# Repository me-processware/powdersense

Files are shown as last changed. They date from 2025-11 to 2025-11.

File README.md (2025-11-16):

# PowderSense - Open Source Precision Measurement System

**Developer**: Processware  
**License**: CERN-OHL-W (Hardware), MIT (Software), CC BY-SA 4.0 (Documentation)  
**Version**: 1.0  
**Status**: Active Development

---

## 📸 Product Overview

<p align="center">
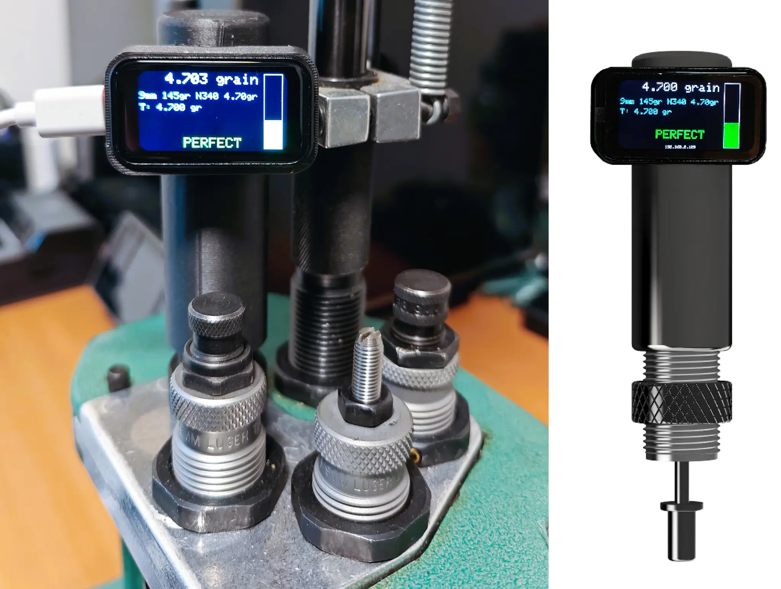
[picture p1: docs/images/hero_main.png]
PowderSense in Action
  
</p>

**PowderSense** mounted on a reloading press, showing real-time precision measurement with visual feedback. The device features a 1.47" color display, WiFi connectivity, and professional PLA-CF enclosure.

---

## 🕹️ Display States

<p align="center">
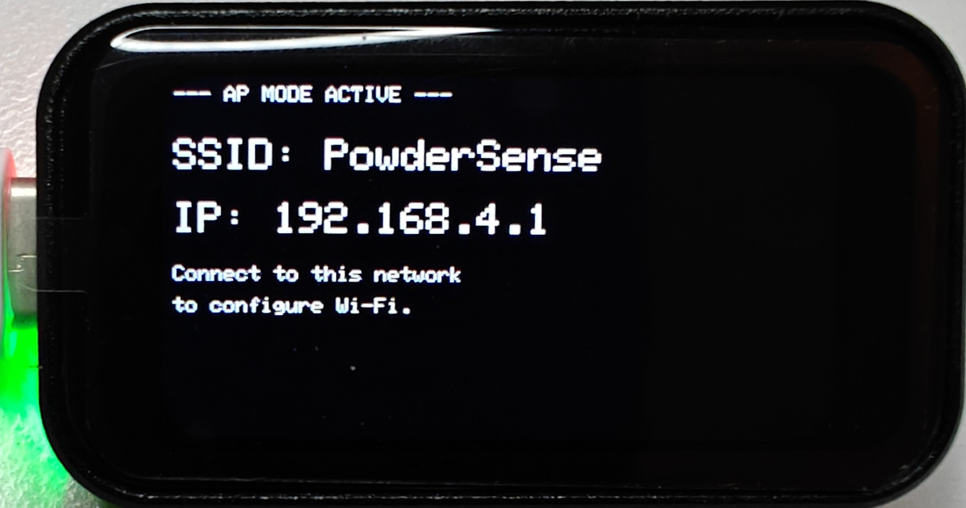
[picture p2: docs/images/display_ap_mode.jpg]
AP Mode
  
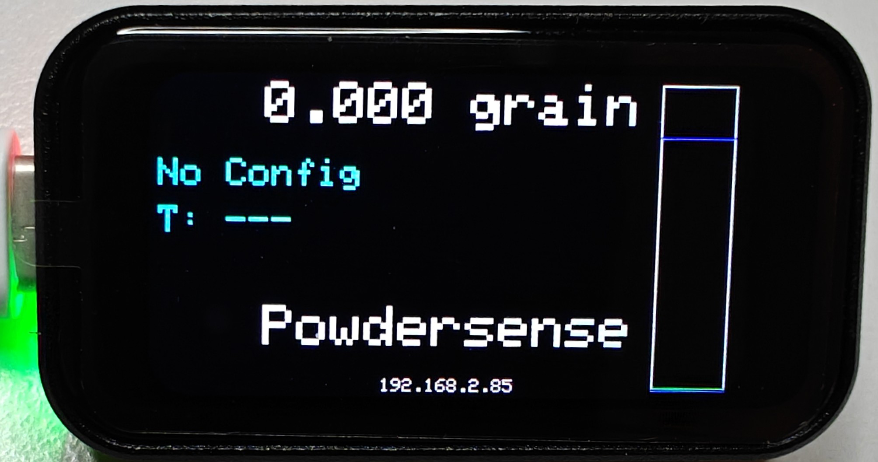
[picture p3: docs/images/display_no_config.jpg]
No Config
  
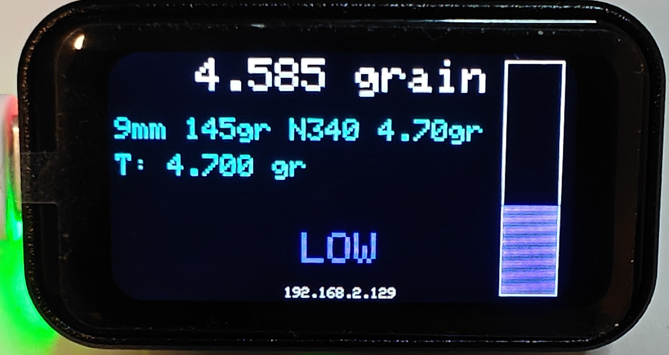
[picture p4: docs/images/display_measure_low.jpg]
Measure Low
  
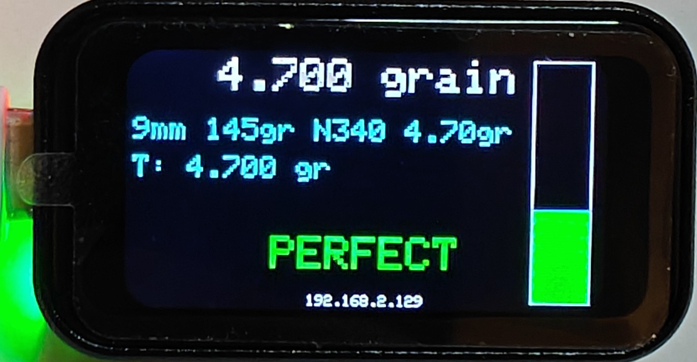
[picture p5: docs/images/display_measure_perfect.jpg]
Measure Perfect
  
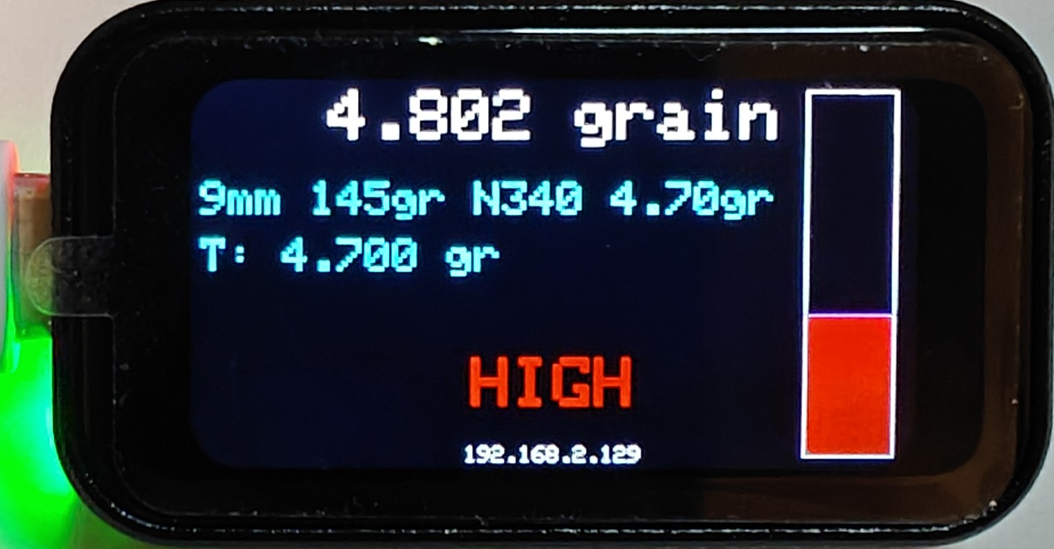
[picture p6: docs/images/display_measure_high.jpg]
Measure High
  
</p>

**5 Operational States**:
1. **AP Mode** - Initial WiFi setup (SSID: PowderSense, IP: 192.168.4.1)
2. **No Config** - Connected but no profile loaded (0.000 grain, "No Config")
3. **Measure LOW** - Below target (4.585 gr, Target: 4.700 gr, blue bar)
4. **Measure PERFECT** - Within tolerance (4.700 gr, Target: 4.700 gr, green bar)
5. **Measure HIGH** - Above target (4.802 gr, Target: 4.700 gr, red bar)

---

## 🎯 Project Overview

PowderSense is an open source precision linear displacement measurement system, originally designed for ammunition reloading applications but adaptable for various industrial and educational purposes. The system combines high-precision analog measurement with modern IoT capabilities, providing real-time monitoring, data logging, and web-based configuration.

---

## 🛒 Get PowderSense

### 🔧 Build It Yourself (Open Source)

All design files, firmware, and documentation are freely available:
- **Hardware**: 3D printable enclosure, schematics, PCB files
- **Firmware**: Complete ESP32-C6 source code
- **Documentation**: Assembly guide, BOM, user manual
- **Cost**: ~€55 in components (see [BOM.md](docs/BOM.md))
- **Time**: 4-6 hours assembly + calibration

### 📦 Pre-Built Units (by Processware)

Don't want to build? Get a fully assembled and tested unit:

**PowderSense Assembled**
- €149,- (excl. shipping)
- Fully assembled and tested
- Includes calibration guide (user must calibrate for their specific application)
- Includes USB-C cable
- 1 year warranty
- Email support: info@processware.nl

**What's Included**:
- Complete assembled device
- 3D printed PLA-CF enclosure (matte black)
- Pre-loaded firmware (latest version)
- Calibration guide and quick start instructions
- Access to web-based user manual

**Shipping**:
- Netherlands: €6.95 (PostNL)
- EU: €12.95 (tracked)
- Worldwide: Contact for quote

**Order**: Email info@processware.nl with:
- Quantity
- Shipping address

*Note: Each application requires specific calibration. The device ships ready to power on, but you must perform calibration for your specific use case following the included guide.*

*Note: By purchasing a pre-built unit, you support continued development of this open source project!*

---

### Key Features

- **High Precision**: 0.0146mm theoretical precision using 16-bit ADC (ADS1115)
- **60mm Measurement Range**: Suitable for depth/displacement measurements
- **WiFi Connectivity**: Real-time monitoring via web interface
- **Data Logging**: Persistent storage with CSV export capability
- **Visual Feedback**: 1.47" TFT LCD display (ST7789) with touch interface *(not implemented yet)*
- **Configurable Thresholds**: Customizable alarm settings for quality control
- **Automatic Measurement**: Stability detection for hands-free operation
- **Multiple Configurations**: Store and switch between different measurement profiles
- **OTA Updates**: Over-the-air firmware updates for easy maintenance *(future implementation)*

---

## 🔧 Hardware Components

### Core Components

| Component | Specification | Purpose |
|---|---|---|
| Microcontroller | ESP32-C6 (Waveshare LCD 1.47) | Main processor with WiFi |
| Display | 1.47" TFT LCD (ST7789, 172x320) | User interface |
| ADC | ADS1115 (16-bit, I2C) | Precision analog measurement |
| Position Sensor | 10kΩ Slide Potentiometer (60mm) | Linear displacement sensing |

### Recommended Potentiometer

**Bourns PTA6043-2015DPB103**
- Travel: 60mm
- Resistance: 10kΩ
- Linearity: ±0.25%
- Mechanical Life: 1 million cycles

### Bill of Materials (BOM)

See [BOM.md](docs/BOM.md) for complete component list with supplier links and pricing.

---

## 📊 Technical Specifications

| Parameter | Value |
|---|---|
| Measurement Range | 0-60mm |
| Resolution | 0.0146mm (theoretical) |
| Accuracy | ±0.1mm (after calibration) |
| Sampling Rate | 10 Hz (adjustable) |
| Display Update | 10 Hz |
| WiFi | 802.11 b/g/n (2.4GHz) |
| Power Supply | 5V USB-C |
| Operating Temperature | 0-50°C |
| Storage | 4MB Flash (SPIFFS) |
| Connectivity | WiFi, USB Serial |

---

## 🚀 Getting Started

Choose your preferred method:

### Option A: Flash Pre-Built Firmware (Easiest)

**For users who just want to use PowderSense without compiling**:

1. **Download** pre-built firmware from [`releases/v1.0/`](releases/v1.0/)
2. **Install** esptool: `pip install esptool`
3. **Connect** ESP32-C6 board via USB-C
4. **Flash** firmware:
   ```bash
   esptool.py --chip esp32c6 --port COM3 write_flash 0x10000 firmware.bin
   esptool.py --chip esp32c6 --port COM3 write_flash 0x290000 spiffs.bin
   ```
5. **Configure** WiFi and start using!

**See**: [releases/v1.0/FLASHING.md](releases/v1.0/FLASHING.md) for detailed instructions

---

### Option B: Build from Source (For Developers)

**For users who want to modify the code or compile themselves**:

#### Prerequisites

- **PlatformIO** (recommended) or Arduino IDE
- **Visual Studio Code** with PlatformIO extension
- **USB-C cable** for programming
- **WiFi network** for web interface access

#### Build and Flash Guide

#### Step 1: Install Prerequisites (Windows)

1. **Install Visual Studio Code**
   - Download from: https://code.visualstudio.com/
   - Run installer and follow prompts

2. **Install PlatformIO Extension**
   - Open VS Code
   - Click Extensions icon (left sidebar) or press `Ctrl+Shift+X`
   - Search for "PlatformIO IDE"
   - Click "Install" on the official PlatformIO extension
   - Wait for installation to complete (may take a few minutes)
   - Restart VS Code when prompted

3. **Install Git** (if not already installed)
   - Download from: https://git-scm.com/download/win
   - Run installer with default settings

4. **Install USB Drivers** (ESP32-C6)
   - Most modern Windows versions auto-detect USB serial
   - If needed: Download CH340/CP2102 drivers from device manufacturer

#### Step 2: Clone and Open Project

1. **Clone Repository**
   
   **Option A: Using Git Bash**
   ```bash
   git clone https://github.com/me-processware/powdersense.git
   cd powdersense
   ```
   
   **Option B: Using VS Code**
   - Press `Ctrl+Shift+P`
   - Type "Git: Clone"
   - Enter: `https://github.com/me-processware/powdersense.git`
   - Select folder location

2. **Open Project in VS Code**
   - File → Open Folder
   - Navigate to `powdersense` directory
   - Click "Select Folder"
   - PlatformIO will automatically detect `platformio.ini`
   - Wait for PlatformIO to initialize (status bar shows progress)

#### Step 3: Build the Firmware

1. **Select Environment**
   - Click PlatformIO icon in left sidebar (alien head)
   - Expand "esp32c6_touch" environment
   - This is the default for Waveshare ESP32-C6 1.47" LCD

2. **Build Project**
   - Click "Build" under esp32c6_touch environment
   - **OR** click checkmark (✓) icon in bottom status bar
   - **OR** press `Ctrl+Alt+B`
   - Wait for compilation (first build takes longer)
   - Success message: "SUCCESS" in terminal

#### Step 4: Upload to Device

1. **Connect ESP32-C6 Board**
   - Connect USB-C cable to ESP32-C6 board
   - Connect other end to PC
   - Windows should detect device (check Device Manager)
   - Note the COM port (e.g., COM3, COM4)

2. **Upload Firmware**
   - Click "Upload" under esp32c6_touch environment
   - **OR** click arrow (→) icon in bottom status bar
   - **OR** press `Ctrl+Alt+U`
   - PlatformIO auto-detects COM port
   - Wait for upload (progress shown in terminal)
   - Device will reboot automatically

3. **Monitor Serial Output**
   - Click "Monitor" under esp32c6_touch
   - **OR** click plug icon in bottom status bar
   - **OR** press `Ctrl+Alt+S`
   - Baud rate: 115200 (auto-configured)
   - Watch boot messages and WiFi status

#### Step 5: Upload Web Interface Files

1. **Build Filesystem Image**
   - In PlatformIO sidebar
   - Expand "Platform" → "Build Filesystem Image"
   - Click to build SPIFFS image from `data/` folder
   - Wait for completion

2. **Upload Filesystem**
   - Click "Upload Filesystem Image" under Platform
   - **OR** in terminal: `pio run -t uploadfs`
   - This uploads HTML/CSS/JS files to device
   - Takes ~30 seconds
   - Device reboots after upload

#### Step 6: Configure WiFi

1. **Access Point Mode**
   - After first boot, device creates WiFi AP
   - SSID: "PowderSense-XXXX" (XXXX = last 4 MAC digits)
   - Password: "powdersense"

2. **Connect to AP**
   - On your phone/laptop, connect to PowderSense WiFi
   - Captive portal should open automatically
   - If not, navigate to: `http://192.168.4.1`

3. **Configure WiFi**
   - Select your WiFi network from dropdown
   - Enter WiFi password
   - Click "Save Configuration"
   - Device reboots and connects to your network

#### Step 7: Access Web Interface

1. **Find Device IP**
   - Check serial monitor for IP address
   - **OR** check your router's DHCP client list
   - **OR** use network scanner (e.g., Advanced IP Scanner)

2. **Open Web Dashboard**
   - Open web browser (Chrome, Firefox, Edge)
   - Navigate to: `http://<device-ip>`
   - Example: `http://192.168.1.100`
   - Web interface loads

3. **Calibrate and Use**
   - Follow on-screen calibration wizard
   - See [USER_MANUAL.md](docs/USER_MANUAL.md) for details

### Detailed Setup

See [SETUP.md](docs/SETUP.md) for comprehensive installation and configuration instructions.

---

## 📖 Documentation

### User Documentation

- [User Manual](docs/USER_MANUAL.md) - Complete operating instructions
- [Calibration Guide](docs/CALIBRATION.md) - Step-by-step calibration procedure
- [Web Interface Guide](docs/WEB_INTERFACE.md) - Using the web dashboard
- [Troubleshooting](docs/TROUBLESHOOTING.md) - Common issues and solutions

### Developer Documentation

- [Architecture Overview](docs/ARCHITECTURE.md) - System design and structure
- [API Reference](docs/API.md) - WebSocket and HTTP endpoints
- [Hardware Assembly](docs/ASSEMBLY.md) - Physical construction guide
- [Firmware Development](docs/DEVELOPMENT.md) - Contributing to firmware
- [PCB Design](hardware/README.md) - Custom PCB schematics and layout

### Application Notes

- [Reloading Application](docs/applications/RELOADING.md) - Ammunition reloading use case
- [Industrial QC](docs/applications/INDUSTRIAL.md) - Quality control applications
- [3D Printer Integration](docs/applications/3D_PRINTING.md) - Bed leveling and monitoring
- [Educational Use](docs/applications/EDUCATION.md) - Teaching measurement principles

---

## 🏗️ Project Structure

```
powdersense/
├── src/                    # Main source code
│   ├── main.cpp           # Application entry point
│   └── board_config.h     # Board-specific pin definitions
├── include/               # Header files
├── lib/                   # Custom libraries
├── data/                  # Web interface files (SPIFFS)
│   ├── index.html        # Main web dashboard
│   ├── wifi_config.html  # WiFi configuration page
│   └── app.py            # (Optional) Python test server
├── hardware/              # Hardware design files
│   ├── schematics/       # Circuit diagrams
│   ├── pcb/              # PCB layouts (KiCad)
│   └── enclosure/        # 3D printable case (STL)
├── docs/                  # Documentation
├── scripts/               # Utility scripts
├── partitions/            # ESP32 partition tables
├── platformio.ini         # PlatformIO configuration
├── LICENSE-HARDWARE.txt   # CERN-OHL-W license
├── LICENSE-SOFTWARE.txt   # MIT license
└── README.md             # This file
```

---

## 🔐 Licensing

This project uses multiple licenses for different components:

### Hardware (CERN-OHL-W)

All hardware designs, schematics, PCB layouts, and mechanical drawings are licensed under the **CERN Open Hardware License Version 2 - Weakly Reciprocal** (CERN-OHL-W).

**What this means**:
- ✅ You can use, modify, and distribute the hardware design
- ✅ You can manufacture and sell products based on this design
- ✅ You can integrate this design into proprietary products
- ⚠️ Modifications to the hardware design itself must be shared under CERN-OHL-W
- ⚠️ You must provide attribution to the original project

See [LICENSE-HARDWARE.txt](LICENSE-HARDWARE.txt) for full terms.

### Software (MIT)

All firmware, software libraries, and utility scripts are licensed under the **MIT License**.

**What this means**:
- ✅ You can use, modify, and distribute the software
- ✅ You can use it in proprietary products
- ✅ You can sublicense and sell it
- ⚠️ You must include the original copyright notice
- ⚠️ No warranty provided

See [LICENSE-SOFTWARE.txt](LICENSE-SOFTWARE.txt) for full terms.

### Documentation (CC BY-SA 4.0)

All documentation, tutorials, and guides are licensed under **Creative Commons Attribution-ShareAlike 4.0 International** (CC BY-SA 4.0).

**What this means**:
- ✅ You can use, adapt, and share the documentation
- ✅ You can use it for commercial purposes
- ⚠️ You must provide attribution
- ⚠️ Derivative works must use the same license

See [LICENSE-DOCUMENTATION.txt](LICENSE-DOCUMENTATION.txt) for full terms.

### Trademark

The name "PowderSense" and associated logos are trademarks of Processware. You may use them to refer to this project, but not to imply endorsement or create confusion about the source of derivative products.

---

## 🛠️ Development

### Building from Source

**Requirements**:
- PlatformIO Core 6.0+
- ESP32 platform package
- Python 3.7+ (for scripts)

**Build Commands**:
```bash
# Build firmware
pio run -e esp32c6_touch

# Upload firmware
pio run -e esp32c6_touch -t upload

# Upload filesystem
pio run -e esp32c6_touch -t uploadfs

# Monitor serial output
pio device monitor -b 115200

# Clean build
pio run -t clean
```

### Development Workflow

1. Create feature branch: `git checkout -b feature/your-feature`
2. Make changes and test thoroughly
3. Update documentation if needed
4. Commit with clear messages
5. Push and create pull request

### Code Style

- **C++**: Follow Arduino style guide
- **Indentation**: 2 spaces (no tabs)
- **Comments**: Explain why, not what
- **Naming**: camelCase for variables, PascalCase for classes

### Testing

- Verify web interface on multiple browsers
- Check calibration accuracy with known references
- Test WiFi connectivity in different scenarios

---

## 🤝 Contributing

Contributions are welcome! This is an open source project and benefits from community input.

### Ways to Contribute

- **Bug Reports**: Open an issue with detailed reproduction steps
- **Feature Requests**: Describe the use case and proposed solution
- **Code Contributions**: Submit pull requests with improvements
- **Documentation**: Help improve guides and tutorials
- **Hardware Variants**: Share adaptations for different sensors/displays
- **Application Notes**: Document new use cases

### Contribution Guidelines

1. **Search existing issues** before creating new ones
2. **One issue per bug/feature** - don't combine multiple topics
3. **Provide context** - explain why, not just what
4. **Test your changes** - ensure they work on actual hardware
5. **Update documentation** - keep docs in sync with code
6. **Be respectful** - follow code of conduct

See [CONTRIBUTING.md](CONTRIBUTING.md) for detailed guidelines.

---

## 🌍 Community

### Get Help

- **GitHub Issues**: Bug reports and feature requests
- **GitHub Discussions**: Questions, ideas, and general chat
- **Email**: info@processware.nl (for private inquiries)

### Share Your Build

We'd love to see what you create! Share your builds:

- Post photos/videos in GitHub Discussions
- Tag #PowderSense on social media
- Submit to Hackaday.io, Hackster.io
- Write blog posts and tutorials

### Stay Updated

- **Watch** this repository for updates
- **Star** if you find it useful
- **Fork** to create your own variant
- Subscribe to release notifications

---

## 📈 Roadmap

### Current Version (v1.0)

- ✅ Basic measurement and display
- ✅ WiFi configuration and web interface
- ✅ Data logging and CSV export
- ✅ Automatic measurement with stability detection
- ✅ Multiple configuration profiles

### Planned Features (v1.x)

- [ ] OTA implementation
- [ ] touchscreen support

## 🎓 Use Cases

### Primary: Ammunition Reloading

Monitor powder depth in reloading presses to detect under/overcharges, ensuring safety and consistency.

**Benefits**:
- Real-time feedback during reloading
- Automatic detection of anomalies
- Data logging for quality records
- Eliminates manual checking

### Industrial Quality Control

Measure part dimensions, material thickness, or fill levels in manufacturing.

**Benefits**:
- High precision at low cost
- WiFi connectivity for remote monitoring
- Data export for SPC analysis
- Customizable for specific applications

### 3D Printing

Monitor bed level, Z-axis position, or filament diameter.

**Benefits**:
- Automated bed leveling assistance
- Print quality monitoring
- Filament consistency checking
- Integration with OctoPrint/Klipper

### Education

Teach measurement principles, calibration, and data analysis.

**Benefits**:
- Open source for learning
- Affordable for schools
- Hands-on electronics project
- Real-world engineering example

---

## 🏆 Acknowledgments

### Inspiration

This project was inspired by the open source hardware movement and successful projects like:

- **Arduino** - Pioneering open source microcontroller platform
- **Adafruit** - Open source hardware and excellent documentation
- **SparkFun** - Community-driven electronics development

### Libraries Used

- **LovyanGFX** - High-performance graphics library
- **WebSockets** - Real-time communication
- **ArduinoJson** - JSON parsing and serialization
- **Adafruit ADS1X15** - ADC driver

---

## 📞 Support

### Commercial Support

For businesses requiring:
- Custom firmware development
- Hardware adaptations
- Integration services
- Training and consulting
- Priority support

Contact: info@processware.nl

### Consulting Services

Processware offers consulting for:
- Industrial measurement systems
- IoT device development
- ESP32 firmware development
- Open source hardware strategy

---

## ⚖️ Disclaimer

This device is provided as-is for educational and experimental purposes. While designed for precision measurement, it should not be used as the sole safety mechanism in critical applications. 

**For reloading applications**: Always follow safe reloading practices, use published load data, and verify charges with a calibrated scale. This device is a supplementary tool, not a replacement for proper reloading procedures.

**No warranty**: This hardware and software are provided without warranty of any kind. Use at your own risk.

---

## 📄 Citation

If you use this project in academic work, please cite:

```
Processware. (2025). PowderSense: Open Source Precision Measurement System.
GitHub repository: https://github.com/me-processware/powdersense
```

---

**Made with ❤️ by Processware**

*Open Source Hardware • Community Driven • Built for Makers*

---

## 🔗 Links

- **GitHub**: https://github.com/me-processware/powdersense
- **Website**: https://powdersense.nl (TBD)
- **Documentation**: https://docs.powdersense.com (TBD)
- **Hackaday**: https://hackaday.io/project/powdersense (TBD)

---

*Last updated: November 2025*

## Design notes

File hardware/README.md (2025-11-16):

# PowderSense Hardware Documentation

**Designer**: Processware  
**License**: CERN-OHL-W  
**Version**: 1.0

---

## 📁 Directory Structure

```
hardware/
├── README.md              # This file
├── enclosure/             # 3D printable case files
│   ├── README.md         # Detailed printing and assembly instructions
│   ├── *.3mf             # Print-ready 3MF files
│   ├── *.stl             # Individual STL files (coming soon)
│   └── source/           # Original CAD files (Fusion 360, STEP)
├── schematics/           # Circuit diagrams and wiring (coming soon)
│   ├── main_schematic.pdf
│   └── wiring_diagram.pdf
└── pcb/                  # Custom PCB design files (future)
    ├── gerbers/
    └── kicad/
```

---

## 🔌 Hardware Overview

### Core Components

The PowderSense system is built around readily available development boards and modules:

**Main Controller**:
- **Waveshare ESP32-C6-LCD-1.47** development board
  - ESP32-C6 microcontroller with WiFi
  - Integrated 1.47" ST7789 TFT LCD (172x320 pixels)
  - USB-C programming and power
  - Compact form factor

**Precision Measurement**:
- **ADS1115** 16-bit ADC module (I2C interface)
  - 4 differential or 8 single-ended inputs
  - Programmable gain amplifier (PGA)
  - 860 samples/second max
  - I2C address: 0x48 (default)

**Position Sensor**:
- **10kΩ Linear Slide Potentiometer** (60mm travel)
  - Recommended: Bourns PTA6043-2015DPB103
  - Linearity: ±0.25%
  - Mechanical life: 1 million cycles
  - Alternatives: Any 60mm linear pot with similar specs

**Optional**:
- **WS2812B RGB LED** (on some board variants)
- **Touch interface** or **4x tactile buttons** (board dependent)

### Bill of Materials (BOM)

For a complete list of components with part numbers, suppliers, and pricing, see:
- [BOM.md](../docs/BOM.md) - Detailed bill of materials

---

## 🛠️ Assembly

### Quick Start

1. **Print Enclosure**: See [enclosure/README.md](enclosure/README.md)
2. **Gather Components**: Order parts from BOM
3. **Solder Connections**: Follow wiring diagram (coming soon)
4. **Install in Case**: Follow assembly instructions in enclosure README
5. **Upload Firmware**: See main project README
6. **Calibrate**: Follow calibration guide

### Detailed Instructions

For step-by-step assembly with photos:
- [Assembly Guide](../docs/ASSEMBLY.md) (coming soon)

---

## 📐 Schematics

### Wiring Overview

**ESP32-C6 to ADS1115 (I2C)**:
- SDA → GPIO4 (or board-specific I2C pin)
- SCL → GPIO5 (or board-specific I2C pin)
- VCC → 3.3V
- GND → GND

**ADS1115 to Potentiometer**:
- A0 → Potentiometer wiper (center pin)
- GND → Potentiometer ground (one end)
- 3.3V → Potentiometer VCC (other end)

**Power**:
- USB-C → ESP32-C6 board (5V input)
- Board regulates to 3.3V for peripherals

### Full Schematics

Detailed circuit diagrams will be added to `schematics/` directory:
- Main schematic (PDF)
- Wiring diagram with color codes
- PCB layout (if custom board developed)

---

## 🔧 Hardware Variants

### Board Configurations

The firmware supports two ESP32-C6 board variants:

**Variant 1: Touch Interface** (Default)
- Touch-enabled display
- No RGB LED
- Pins: SCLK=1, MOSI=2, DC=15, CS=14, RST=22, BL=23
- ADC on GPIO5

**Variant 2: RGB LED**
- 4x physical buttons
- WS2812B RGB LED on GPIO8
- Pins: SCLK=7, MOSI=6, DC=15, CS=14, RST=21, BL=22
- ADC on GPIO2

See `platformio.ini` for build configuration.

### Sensor Options

**Standard**: 10kΩ potentiometer with ADS1115 (16-bit)
- Resolution: 0.0146mm theoretical
- Accuracy: ±0.1mm after calibration

**Alternative**: Direct ESP32 ADC (12-bit)
- Lower cost (no ADS1115 needed)
- Reduced precision: ~0.15mm
- Sufficient for many applications

**Future**: Non-contact sensors
- Ultrasonic distance sensor
- Laser ToF sensor
- Magnetic linear encoder

---

## 🎨 Customization

### Mechanical Adaptations

The enclosure design can be modified for:
- Different display sizes
- Alternative mounting methods
- Integration with specific equipment
- Ruggedized versions for harsh environments

**Source files provided**:
- Fusion 360 (.f3d) in `enclosure/source/`
- STEP format (.step) for universal compatibility

### Electrical Modifications

**Possible enhancements**:
- Battery power (LiPo + charging circuit)
- External sensor inputs
- Relay outputs for automation
- RS-485 for industrial networks
- Ethernet module for wired connectivity

**Community contributions welcome!**

---

## 📏 Specifications

### Mechanical

| Parameter | Value |
|---|---|
| Enclosure Dimensions | 120 x 80 x 45 mm (approx) |
| Weight (assembled) | ~200g |
| Mounting | Desktop, wall-mount, or custom |
| Ingress Protection | IP20 (indoor use) |

### Electrical

| Parameter | Value |
|---|---|
| Input Voltage | 5V DC (USB-C) |
| Power Consumption | <1W typical, <2W max |
| Operating Temperature | 0-50°C |
| Storage Temperature | -20 to 70°C |
| Humidity | 20-80% RH (non-condensing) |

### Measurement

| Parameter | Value |
|---|---|
| Range | 0-60mm (potentiometer dependent) |
| Resolution | 0.0146mm (16-bit ADC) |
| Accuracy | ±0.1mm (after calibration) |
| Repeatability | ±0.05mm |
| Sampling Rate | 10 Hz (configurable) |

---

## 🔐 License

All hardware designs in this directory are licensed under:

**CERN Open Hardware License Version 2 - Weakly Reciprocal (CERN-OHL-W)**

This means:
- ✅ You can use, modify, and sell products based on this design
- ✅ You can integrate into proprietary products
- ⚠️ Modifications to the hardware design must be shared under CERN-OHL-W
- ⚠️ Attribution to Processware required

Full license: [LICENSE-HARDWARE.txt](../LICENSE-HARDWARE.txt)

---

## 🤝 Contributing

### Hardware Contributions Welcome

We're looking for:
- **PCB designs**: Custom board layouts
- **Enclosure variants**: Different sizes, mounting options
- **Sensor adaptations**: Alternative measurement methods
- **Improvements**: Better cable management, cooling, etc.

### How to Contribute

1. Fork the repository
2. Create your hardware modification
3. Document thoroughly (schematics, BOM, photos)
4. Test and verify functionality
5. Submit pull request

See [CONTRIBUTING.md](../CONTRIBUTING.md) for detailed guidelines.

---

## 📞 Support

**Hardware questions?**

- GitHub Issues: Technical problems
- GitHub Discussions: Design questions
- Email: info@processware.nl

**Share your build!**

Post photos and modifications in GitHub Discussions or tag #PowderSense on social media.

---

## 🎯 Future Development

### Planned Hardware Improvements

**Short-term**:
- [ ] Custom PCB design (integrate ESP32 + ADS1115)
- [ ] Professional schematics in KiCad
- [ ] Multiple enclosure size options
- [ ] Improved cable management

**Long-term**:
- [ ] Battery-powered version
- [ ] Industrial-grade sensors
- [ ] Multi-sensor support
- [ ] Modular expansion system

See [ROADMAP.md](../docs/ROADMAP.md) for full development plan.

---

## 🙏 Acknowledgments

**Component Manufacturers**:
- Waveshare - ESP32-C6-LCD development board
- Texas Instruments - ADS1115 ADC
- Bourns - High-quality potentiometers

**Design Tools**:
- Autodesk Fusion 360 - Mechanical design
- KiCad - Electronics design (planned)

---

*Hardware designed by Processware - November 2025*  
*Part of the PowderSense Open Source Project*

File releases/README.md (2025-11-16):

# PowderSense Pre-Built Firmware Releases

This directory contains pre-built firmware binaries for users who want to flash PowderSense without compiling from source.

---

## 📦 Available Releases

### [v1.0](v1.0/) - Latest Stable

**Release Date**: November 2025  
**Status**: Stable

**What's New**:
- Initial open source release
- ESP32-C6 support with 1.47" LCD
- WiFi configuration via Access Point
- Web-based dashboard and configuration
- Multi-profile support
- Data logging with CSV export
- Automatic measurement with stability detection

**Files**:
- `firmware.bin` - Main application firmware (~1.2MB)
- `spiffs.bin` - Web interface files (~1.5MB)
- `FLASHING.md` - Detailed flashing instructions

**Quick Flash**:
```bash
esptool.py --chip esp32c6 --port COM3 write_flash 0x10000 firmware.bin
esptool.py --chip esp32c6 --port COM3 write_flash 0x290000 spiffs.bin
```

---

## 🚀 Quick Start

### Option 1: Pre-Built Binaries (This Directory)

**For users who want to flash without compiling**:

1. **Download** firmware from `releases/v1.0/`
2. **Install** esptool: `pip install esptool`
3. **Connect** ESP32-C6 via USB
4. **Flash** firmware:
   ```bash
   cd releases/v1.0
   esptool.py --chip esp32c6 --port COM3 write_flash 0x10000 firmware.bin
   esptool.py --chip esp32c6 --port COM3 write_flash 0x290000 spiffs.bin
   ```
5. **Configure** WiFi via Access Point
6. **Calibrate** and start measuring

**See**: [v1.0/FLASHING.md](v1.0/FLASHING.md) for detailed instructions

---

### Option 2: Compile from Source

**For developers who want to modify the code**:

1. **Clone** repository
2. **Install** PlatformIO + VS Code
3. **Build** and upload
4. **See**: Main [README.md](../README.md) for build instructions

---

## 🔄 Updating Firmware

**To update to a newer version**:
1. Download new firmware binaries
2. Flash using same commands
3. WiFi credentials and calibration are preserved

**To do a clean install**:
```bash
esptool.py --chip esp32c6 --port COM3 erase_flash
# Then flash firmware + spiffs
```

---

## 📋 Version History

| Version | Date | Status | Notes |
|---|---|---|---|
| v1.0 | Nov 2025 | Stable | Initial open source release |

---

## 🛠️ Hardware Requirements

- **Board**: Waveshare ESP32-C6 1.47" LCD (touch version)
- **USB**: USB-C cable (data capable)
- **Drivers**: CH340/CP2102 (usually auto-detected)

---

## 📖 Documentation

- **Flashing Guide**: [v1.0/FLASHING.md](v1.0/FLASHING.md)
- **User Manual**: [docs/USER_MANUAL.md](../docs/USER_MANUAL.md)
- **Assembly Guide**: [docs/ASSEMBLY.md](../docs/ASSEMBLY.md)
- **BOM**: [docs/BOM.md](../docs/BOM.md)

---

## 🆘 Support

**Issues with flashing?**
- Check [FLASHING.md](v1.0/FLASHING.md) troubleshooting section
- GitHub Issues: https://github.com/me-processware/powdersense/issues
- Email: info@processware.nl

---

## 🔐 Verification

All binaries are built from tagged releases in this repository. You can verify by:
1. Checking out the corresponding git tag
2. Building from source with PlatformIO
3. Comparing binary checksums

**Build Environment**:
- PlatformIO Core 6.1.15
- ESP-IDF framework
- GCC 11.2.0

---

*Pre-built binaries by Processware*  
*Part of the PowderSense Open Source Project*

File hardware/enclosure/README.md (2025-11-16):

# PowderSense Enclosure - 3D Printable Case

**Designer**: Processware  
**Version**: 2.0  
**License**: CERN-OHL-W  
**Last Updated**: November 2025

---

## 📦 Overview

This directory contains 3D-printable enclosure files for the PowderSense precision measurement system. The design is optimized for FDM printing and provides a professional, functional housing for all electronic components.

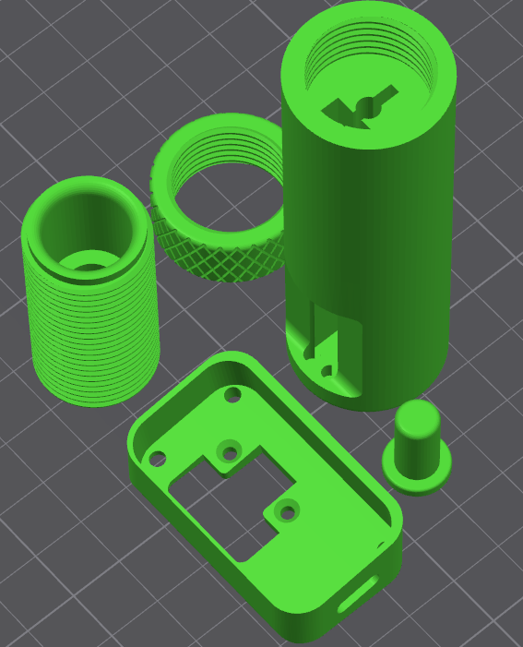
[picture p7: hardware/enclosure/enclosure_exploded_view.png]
Enclosure Exploded View

*Exploded view showing all 5 printable components*

**Components shown (left to right, top to bottom)**:
1. **Probe Cap** (top left) - Threaded cap with M4 insert for probe attachment
2. **Display Bezel** (middle) - Knurled ring to secure 1.47" LCD display
3. **Main Body** (top right) - Primary housing with integrated bearings and cable ducts
4. **Display Housing** (bottom) - Front panel with display cutout and mounting holes
5. **Probe End Cap** (bottom right) - Small cap for probe tip

**Design Features:**
- Compact form factor optimized for RCBS 2000 Pro integration
- Integrated display bezel for 1.47" TFT LCD
- Secure mounting for ESP32-C6 board and ADS1115 ADC
- Cable management and strain relief
- Easy assembly with minimal hardware
- Ventilation for heat dissipation
- Professional appearance suitable for workshop use

---

## 🖨️ Quick Start

### For Immediate Printing

**Download**: `powdersense_main_offset_displayv2.3mf`

This file contains all components pre-oriented for optimal printing. Simply:
1. Download the 3MF file
2. Open in your slicer (PrusaSlicer, Cura, Bambu Studio)
3. Slice with recommended settings (see below)
4. Print!

**Estimated Print Time**: 6-8 hours (depending on printer speed)  
**Material Required**: ~120-150g filament

---

## ⚙️ Recommended Print Settings

### Material

**Primary Recommendation: PETG**
- Temperature resistance: Better than PLA
- Durability: Excellent impact resistance
- Layer adhesion: Superior strength
- Workshop environment: Handles temperature variations

**Alternative: PLA**
- Easier to print
- Good for indoor/climate-controlled use
- Lower temperature resistance
- Adequate for most applications

**Not Recommended: ABS**
- Requires enclosure and heated bed
- Warping issues
- Fumes require ventilation
- Unnecessary for this application

### Slicer Settings

| Setting | Value | Notes |
|---|---|---|
| **Layer Height** | 0.2mm | Good balance of speed and quality |
| **Initial Layer** | 0.2mm | Standard |
| **Infill Density** | 20% | Sufficient strength, saves material |
| **Infill Pattern** | Gyroid or Grid | Gyroid for strength, Grid for speed |
| **Wall Count** | 3-4 perimeters | Ensures structural integrity |
| **Top/Bottom Layers** | 4-5 layers | Solid surfaces |
| **Print Speed** | 50-60 mm/s | Quality over speed |
| **Support** | **None required** | Parts pre-oriented |
| **Brim/Raft** | Optional | Use if bed adhesion is problematic |

### Temperature Settings (PETG)

| Parameter | Temperature |
|---|---|
| **Nozzle** | 230-245°C |
| **Bed** | 70-80°C |
| **Fan** | 30-50% (after first layer) |

### Temperature Settings (PLA)

| Parameter | Temperature |
|---|---|
| **Nozzle** | 200-215°C |
| **Bed** | 50-60°C |
| **Fan** | 100% (after first layer) |

---

## 📋 Parts List

The 3MF file contains the following components:

### Main Components

1. **Main Housing Bottom** - Base enclosure with mounting points
2. **Main Housing Top** - Cover with display cutout
3. **Display Bezel** - Frame for 1.47" TFT LCD
4. **Potentiometer Mount** - Secure mounting for slide potentiometer
5. **Cable Gland/Strain Relief** - Professional cable entry

### Print Orientation

All parts are pre-oriented in the 3MF file for:
- **No supports required**
- **Optimal layer orientation** for strength
- **Best surface finish** on visible faces
- **Minimal bridging**

---

## 🔩 Required Hardware

To complete the assembly, you'll need:

### Fasteners

| Item | Quantity | Specification | Purpose |
|---|---|---|---|
| M3 x 8mm screws | 4 | Pan head or button head | Case assembly |
| M3 x 6mm screws | 4 | Pan head | Display bezel |
| M2.5 x 6mm screws | 4 | Pan head | PCB mounting |
| M3 heat-set inserts | 4 | 4mm OD x 5mm length | Case threads (optional) |

**Note**: Heat-set inserts are optional but recommended for repeated assembly/disassembly.

### Adhesives (Optional)

- **Cyanoacrylate (CA glue)**: For permanent display bezel attachment
- **Hot glue**: For cable strain relief

---

## 🛠️ Assembly Instructions

### Step 1: Post-Processing (Optional)

**Remove supports**: None should be present if using the 3MF file

**Clean parts**:
- Remove any stringing or blobs with hobby knife
- Light sanding (220 grit) on mating surfaces for smooth fit
- Test-fit all parts before final assembly

**Heat-set inserts** (if using):
1. Heat soldering iron to 200-220°C
2. Place insert on hole
3. Apply gentle pressure until flush with surface
4. Allow to cool completely

### Step 2: Electronics Preparation

**Before installing in case**:
1. Solder all connections to ESP32-C6 board
2. Connect ADS1115 ADC module
3. Attach slide potentiometer wiring
4. Test all functions (see main documentation)
5. Upload firmware and verify operation

### Step 3: Main Assembly

**Install PCB in bottom housing**:
1. Route cables through designated channels
2. Secure ESP32-C6 board with M2.5 screws
3. Position ADS1115 module
4. Ensure no wires are pinched

**Mount potentiometer**:
1. Insert slide potentiometer into mount
2. Secure with provided bracket or screws
3. Verify smooth travel over full range

**Cable management**:
1. Route power cable through strain relief
2. Organize internal wiring
3. Use cable ties or hot glue for strain relief

### Step 4: Display Installation

**Attach LCD to bezel**:
1. Carefully insert 1.47" TFT LCD into bezel
2. Ensure screen is centered in cutout
3. Secure with M3 x 6mm screws or CA glue
4. Connect display ribbon cable to ESP32-C6

**Test before closing**:
1. Power on device
2. Verify display shows correctly
3. Check touch functionality (if applicable)
4. Test all buttons/inputs

### Step 5: Final Assembly

**Close enclosure**:
1. Align top and bottom housing
2. Ensure all cables are inside
3. Insert M3 x 8mm screws (or into heat-set inserts)
4. Tighten evenly in cross pattern
5. Do not overtighten (risk of cracking)

**Final checks**:
1. Verify all functions work
2. Check for any rattling (loose components)
3. Inspect seams for gaps
4. Apply labels or markings if desired

---

## 🎨 Customization Options

### Color Schemes

**Professional**:
- Black or dark gray PETG
- White or light gray for contrast
- Matches workshop equipment

**High Visibility**:
- Orange or yellow (safety colors)
- Bright green or blue
- Easy to locate in busy workspace

**Multi-Color**:
- Print bezel in contrasting color
- Use different colors for top/bottom
- Requires filament swap or multi-material printer

### Modifications

**Mounting Options**:
- Add DIN rail clips to bottom
- Magnetic mounts for metal surfaces
- Velcro strips for temporary placement
- Threaded inserts for tripod mount

**Ventilation**:
- Add vent holes if operating in hot environment
- Mesh inserts for dust protection
- Fan mount for active cooling (if needed)

**Labeling**:
- Embossed text (modify CAD file)
- Adhesive labels
- Engraved plates
- Paint or vinyl decals

---

## 📐 Dimensions

| Measurement | Value |
|---|---|
| **Overall Length** | ~120mm |
| **Overall Width** | ~80mm |
| **Overall Height** | ~45mm |
| **Display Opening** | 35mm x 35mm (for 1.47" LCD) |
| **Wall Thickness** | 2.0mm |
| **Weight (printed)** | ~100-120g |

*Note: Exact dimensions may vary slightly based on your specific design iteration*

---

## 🔧 Troubleshooting

### Print Quality Issues

**Warping**:
- Increase bed temperature
- Use brim or raft
- Ensure bed is level and clean
- Reduce cooling fan speed

**Layer adhesion problems**:
- Increase nozzle temperature by 5-10°C
- Reduce print speed
- Check filament quality/moisture
- Calibrate extrusion multiplier

**Stringing**:
- Enable retraction (4-6mm for Bowden, 1-2mm for direct drive)
- Reduce temperature slightly
- Increase retraction speed
- Dry filament if moisture absorbed

**Dimensional accuracy**:
- Calibrate printer (steps/mm, flow rate)
- Check belt tension
- Verify slicer settings
- Scale model by 100.5% if consistently undersized

### Assembly Issues

**Parts don't fit**:
- Check for print defects (blobs, stringing)
- Light sanding on mating surfaces
- Verify correct orientation during assembly
- May need to scale specific parts slightly

**Screws won't thread**:
- Use heat-set inserts instead of direct threading
- Drill out holes slightly if too small
- Use self-tapping screws
- Apply gentle pressure, don't force

**Display doesn't sit flush**:
- Verify LCD dimensions match design
- Check for warping in bezel
- Adjust with thin shims if needed
- Ensure bezel is printed with correct orientation

---

## 📁 File Formats

### Available Files

**3MF Format** (Recommended):
- `powdersense_main_offset_displayv2.3mf` - Complete print-ready file

**STL Format** (Individual parts):
- Coming soon - individual STL exports for flexibility

**Source Files**:
- `source/` directory - Fusion 360 native files (.f3d)
- STEP format (.step) - Universal CAD format for modifications

### Modifying the Design

**If you want to customize**:

1. Download Fusion 360 (free for personal use)
2. Open the .f3d file from `source/` directory
3. Make your modifications
4. Export as 3MF or STL
5. Share your remix! (CERN-OHL-W requires sharing modifications)

**Common modifications**:
- Adjust dimensions for different displays
- Add custom mounting features
- Integrate cable routing channels
- Create variants for different sensors

---

## 🤝 Contributing

**Found an improvement?**

We welcome contributions to the enclosure design!

**How to contribute**:
1. Fork the repository
2. Modify the CAD files
3. Test print your changes
4. Submit a pull request with:
   - Photos of printed parts
   - Description of improvements
   - Updated documentation

**Ideas for contributions**:
- Alternative mounting solutions
- Improved cable management
- Variants for different applications
- Optimizations for faster printing
- Multi-material designs

---

## 📜 License

This enclosure design is licensed under **CERN Open Hardware License Version 2 - Weakly Reciprocal (CERN-OHL-W)**.

**You are free to**:
- Use this design for any purpose
- Modify and improve the design
- Manufacture and sell products using this design

**You must**:
- Provide attribution to Processware
- Share modifications to the design under CERN-OHL-W
- Include a link to the original project

See [LICENSE-HARDWARE.txt](../../LICENSE-HARDWARE.txt) for full license text.

---

## 📞 Support

**Questions about printing or assembly?**

- **GitHub Issues**: Report problems or ask questions
- **GitHub Discussions**: Share your prints and modifications
- **Email**: info@processware.nl

**Share your build!**

We'd love to see your printed enclosures:
- Post photos in GitHub Discussions
- Tag #PowderSense on social media
- Submit to Printables/Thingiverse
- Write a build log

---

## 🎯 Design Philosophy

This enclosure was designed with the following principles:

**Printability First**:
- No supports required
- Minimal bridging
- Forgiving tolerances
- Works on budget printers

**Functionality**:
- Protects electronics
- Professional appearance
- Easy assembly/disassembly
- Practical for workshop use

**Accessibility**:
- Common hardware sizes
- No specialized tools required
- Clear assembly instructions
- Beginner-friendly

**Customizability**:
- Source files provided
- Modular design
- Easy to modify
- Remix-friendly

---

## 📊 Print Statistics

Based on testing with multiple printers:

| Printer Type | Print Time | Material Used | Success Rate |
|---|---|---|---|
| Prusa i3 MK3S | 7h 15m | 135g | 95% |
| Ender 3 V2 | 8h 30m | 142g | 90% |
| Bambu Lab P1P | 5h 45m | 128g | 98% |
| Creality CR-10 | 8h 00m | 138g | 92% |

*Success rate based on first-time prints with recommended settings*

---

## 🔄 Version History

### Version 2.0 (Current)
- Offset display design for improved ergonomics
- Optimized cable routing
- Reduced material usage by 15%
- Improved ventilation
- Better screw accessibility

### Version 1.0
- Initial release
- Basic functional enclosure
- Centered display layout

---

## 🙏 Acknowledgments

**Design Tools**:
- Autodesk Fusion 360 - CAD design
- PrusaSlicer - Testing and slicing
- Bambu Studio - Multi-color variants

---

**Happy Printing!** 🖨️

If you build this enclosure, we'd love to hear about your experience. Share your results and help improve the design for everyone!

---

*Design by Processware - November 2025*  
*Part of the PowderSense Open Source Project*

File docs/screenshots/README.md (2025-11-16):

# PowderSense Screenshots

This directory contains screenshots of the PowderSense web interface for documentation purposes.

## Hardware Components

Located in `docs/images/`:

**bourns_potentiometer.png**
- Bourns PTA6043-2015DPB103 slide potentiometer
- 10kΩ linear, 60mm travel
- Shows full component with mounting holes
- White plastic housing with black slider
- Reference for BOM and assembly guide

**steel_rod_threaded.png**
- 4mm diameter steel rod (85mm length)
- M4 threading visible on one end
- Precision ground silver steel
- Shows finished rod ready for assembly
- Reference for rod preparation in assembly guide

**product_render.png**
- 3D CAD render of assembled device
- Shows complete unit with display
- Green PETG enclosure
- Used in README header

**product_photo.png**
- Real photo of working PowderSense unit
- Mounted on reloading press
- Display showing measurement (4.999 grains)
- "PERFECT" status indicator
- Used in README header and marketing

## Web Interface Screenshots

### Dashboard

**dashboard_main.webp**
- Main dashboard view
- Current measurement display (large)
- Last measurement panel
- Quick settings panel with profile selector
- Session statistics
- Real-time chart area
- Control buttons (Measure, Calibrate, etc.)

**dashboard_advanced.webp**
- Lower section of dashboard
- Session logs table
- Advanced settings panel
- System information
- Recent measurements table
- Configuration management buttons
- Firmware update controls

### Configuration

**profile_dialog.webp**
- Add New Configuration dialog
- Input fields for:
  - Configuration Name
  - Caliber
  - Bullet Weight
  - Powder Name
  - Target Grain
- Save and Cancel buttons

### WiFi Setup

**wifi_config.webp**
- WiFi configuration page (AP mode)
- SSID input field
- Password input field
- Current status display
- Save & Connect button
- Instructions for after saving

## Usage in Documentation

These screenshots are referenced in:
- `docs/USER_MANUAL.md` - User manual with UI walkthroughs
- `README.md` - Project overview and quick start
- `docs/ASSEMBLY.md` - Assembly guide (for web interface setup)

## Adding New Screenshots

When adding new screenshots:
1. Use descriptive filenames (lowercase, underscores)
2. Use WebP format for smaller file sizes
3. Update this README with description
4. Reference in relevant documentation

## Screenshot Details

| Filename | Size | Description |
|---|---|---|
| dashboard_main.webp | 142KB | Main dashboard view |
| dashboard_advanced.webp | 123KB | Advanced settings section |
| profile_dialog.webp | 83KB | Configuration profile dialog |
| wifi_config.webp | 306KB | WiFi setup page (AP mode) |

### Hardware Component Images

| Filename | Size | Description |
|---|---|---|
| bourns_potentiometer.png | 393KB | Bourns 10kΩ 60mm slide potentiometer |
| steel_rod_threaded.png | 594KB | 4mm steel rod with M4 threading |
| product_render.png | 177KB | 3D CAD render of device |
| product_photo.png | 162KB | Real photo of working unit |

---

*Screenshots by Processware - November 2025*  
*Part of the PowderSense Open Source Project*

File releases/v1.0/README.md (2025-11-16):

# PowderSense v1.0 - Pre-Built Firmware

**Release Date**: November 2025  
**Status**: Stable Release

---

## 📦 Files in This Release

### Required for Flashing

| File | Size | Description | Flash Address |
|---|---|---|---|
| `firmware.bin` | ~1.2MB | Main application firmware | 0x10000 |
| `spiffs.bin` | ~1.5MB | Web interface (HTML/CSS/JS) | 0x290000 |

### Optional Reference Files

| File | Description |
|---|---|
| `firmware.elf` | Debug symbols (not needed for flashing) |
| `firmware.map` | Memory map (not needed for flashing) |
| `partitions.csv` | Partition table source |

---

## 🚀 Quick Flash

**Prerequisites**: Install esptool
```bash
pip install esptool
```

**Flash Command**:
```bash
# Flash firmware
esptool.py --chip esp32c6 --port COM3 write_flash 0x10000 firmware.bin

# Flash web interface
esptool.py --chip esp32c6 --port COM3 write_flash 0x290000 spiffs.bin
```

**Note**: Replace `COM3` with your actual port (Windows: COM3, Linux: /dev/ttyUSB0, macOS: /dev/cu.usbserial-*)

---

## 📖 Detailed Instructions

See [FLASHING.md](FLASHING.md) for:
- Complete flashing guide
- Multiple flashing methods (esptool, ESP Flash Tool, PlatformIO)
- Memory address details
- Troubleshooting
- Update procedures

---

## ✨ What's New in v1.0

### Features
- ✅ ESP32-C6 support with 1.47" TFT LCD
- ✅ WiFi configuration via Access Point mode
- ✅ Web-based dashboard with real-time measurements
- ✅ Multi-profile configuration system
- ✅ Data logging with CSV export
- ✅ Automatic measurement with stability detection
- ✅ Visual feedback (color-coded status: LOW/PERFECT/HIGH)
- ✅ Session statistics tracking

### Hardware Support
- **Board**: Waveshare ESP32-C6 1.47" LCD
- **Display**: ST7789 TFT (172x320 pixels)
- **ADC**: ADS1115 16-bit I2C
- **Sensor**: 10kΩ slide potentiometer (60mm travel)

### Known Limitations
- ⚠️ Touch interface not implemented (display only)
- ⚠️ OTA updates not implemented (flash via USB)

---

## 🔧 Hardware Requirements

**Minimum**:
- Waveshare ESP32-C6 1.47" LCD board
- USB-C cable (data capable)
- Computer with USB port

**For Complete System**:
- See [BOM.md](../../docs/BOM.md) for full component list
- See [ASSEMBLY.md](../../docs/ASSEMBLY.md) for build instructions

---

## 📝 First-Time Setup

After flashing:

1. **Power On**: Connect USB-C cable
2. **Access Point**: Device creates "PowderSense-XXXX" WiFi
3. **Connect**: Join the WiFi (password: "powdersense")
4. **Configure**: Navigate to 192.168.4.1 and set WiFi credentials
5. **Reboot**: Device connects to your network
6. **Access**: Open web interface at device IP
7. **Calibrate**: Follow on-screen calibration wizard
8. **Measure**: Start using PowderSense!

**See**: [USER_MANUAL.md](../../docs/USER_MANUAL.md) for detailed setup and usage

---

## 🔄 Updating from Previous Version

**This is the first release**, no previous version exists.

For future updates:
- WiFi credentials will be preserved
- Calibration data will be preserved
- Configuration profiles will be preserved

---

## 🐛 Known Issues

None reported yet. Please report issues at:
https://github.com/me-processware/powdersense/issues

---

## 🆘 Support

**Flashing Problems?**
- See [FLASHING.md](FLASHING.md) troubleshooting section
- Check USB cable (must support data)
- Try lower baud rate: `--baud 115200`

**Usage Questions?**
- Read [USER_MANUAL.md](../../docs/USER_MANUAL.md)
- GitHub Issues: https://github.com/me-processware/powdersense/issues
- Email: info@processware.nl

---

## 📊 Build Information

- **Version**: 1.0
- **Build Date**: November 2025
- **Git Commit**: TBD (will be added when tagged)
- **Platform**: ESP32-C6
- **Framework**: Arduino (ESP-IDF)
- **PlatformIO**: 6.1.15
- **Compiler**: GCC 11.2.0

---

## 🔐 Checksums

**bootloader.bin**:
- MD5: `9985e72399d371ee61de7c4d1d669485`
- SHA256: `a57485bef96b7be694204427b70d920263f076a352956cb0e36b9ffce0fa12a8`

**partitions.bin**:
- MD5: `588df43564950cbb0bd3c5fb5c081df0`
- SHA256: `5233eab607f53cb0d175f13f25cf917e5496e340e2565188cf9550b4080c449c`

**firmware.bin**:
- MD5: `ba6a9b08752c0f15e5bdd31c9f690724`
- SHA256: `f2a37c0f4d5cb3068e576668ed19a5684c8047fa11ae392ddbd338c04efd0115`

**spiffs.bin**:
- MD5: `10b9ae4c20b10dfc378bfb63925f72f4`
- SHA256: `d3db9c5fb5bb24c81f5cb9a64315ccbd27517e52b2513ab54a03e943bd2a8304`

**See [CHECKSUMS.md](CHECKSUMS.md) for detailed verification instructions.**

---

*Pre-built by Processware - November 2025*  
*Part of the PowderSense Open Source Project*

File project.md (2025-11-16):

# Project: Powder Depth Measurement System

## Project Requirements & Status

-   **Measure Depth:** Use a 10k slide potentiometer (60mm travel, Bourns PTA6043-2015DPB103) with a theoretical precision of **0.0146 mm**.
    -   Status: **In Progress** (Initial setup with ESP32 ADC, precision accepted, range corrected)
-   **Presets/Thresholds:** Define depth thresholds.
    -   Status: **To Do**
-   **Logging:** Log entries on the ESP32.
    -   Status: **To Do**
-   **Visual Feedback:** Use green/red LEDs to indicate if thresholds are met.
    -   Status: **To Do**
-   **User Interface:** 1.47-inch TFT LCD screen (ST7789) and 4 buttons to set thresholds, reset etc.
    -   Status: **In Progress** (Display initialized, basic text output implemented)
-   **Persistence:** Store all settings on the ESP32 (EEPROM/SPIFFS).
    -   Status: **To Do**
-   **Data Visualization:** Display measurements in a graph on the TFT LCD.
    -   Status: **To Do**
-   **Data Export:** Download measurements as a CSV file (via web interface).
    -   Status: **In Progress** (Basic web server and data endpoint)
-   **Web Interface:** HTML page to view and track powder loads.
    -   Status: **In Progress** (Basic HTML page served)

## Progress Log

### 2023-10-27
-   Initialized project structure.
-   Created `project.md`, `README.md`, `platformio.ini`, and `src/main.cpp`.
-   Set up basic ESP32 Arduino sketch for potentiometer reading.
-   Identified precision challenge with 10k pot and ESP32 ADC.

### 2023-10-28
-   Confirmed 0.18mm precision is acceptable.
-   Added web interface requirement for viewing and tracking powder loads.
-   Updated `platformio.ini` with Wi-Fi and WebServer libraries.
-   Implemented basic Wi-Fi connectivity and web server in `src/main.cpp`.
-   Created `data/index.html` and `data/style.css` for the web interface.
-   Added API endpoint for current depth data.

### 2023-10-29
-   Corrected potentiometer measurement range from 75cm to 75mm.
-   Temporarily disabled OLED display functionality as it is not currently connected.
-   Added more detailed serial logging for debugging boot process and file serving.

### 2023-10-30
-   Updated potentiometer travel to 60mm based on Bourns PTA6043-2015DPB103 datasheet.
-   Recalculated theoretical precision based on new travel distance.
-   Reviewed `partitions/default_8MB.csv` - no errors found.
-   Reviewed `partitions/default_4MB.csv` - no errors found.
-   Successfully resolved boot loop and SPIFFS mount issues. Device now boots, connects to WiFi, and mounts SPIFFS.
-   Next step: Verify SPIFFS content upload and web page display.

### 2023-11-01
-   **Hardware Change:** Switched from ESP32-S3 to ESP32-C6 1.47-inch LCD development board.
-   Updated `platformio.ini` to target `esp32-c6-devkitc-1` and added `Adafruit_ST7735_and_ST7789_Library`.
-   Modified `src/main.cpp` to initialize and use the ST7789 TFT display instead of SSD1306 OLED.
-   Adjusted display output functions (`setupDisplay`, `displayExampleScreen`, `loop` display logic) for the new screen resolution (172x320) and capabilities.
-   Updated `project.md` to reflect the new hardware and display.

### 2023-11-02
-   **Framework Change:** Migrated from Arduino framework to ESP-IDF for better ESP32-C6 compatibility and direct hardware control.
-   Updated `platformio.ini` to use `framework = espidf`.
-   `src/main.cpp` has been converted to a minimal ESP-IDF application, focusing on basic display initialization. Further application logic (Wi-Fi, WebSockets, etc.) will need to be re-implemented using ESP-IDF APIs.
-   **Pinout Update:** Updated `src/main.cpp`, `README.md`, and `project.md` with verified pin definitions for the Waveshare ESP32-C6-LCD-1.47 board.

## Version History

-   **0.1.0** (2023-10-27): Initial project setup and basic potentiometer reading.
-   **0.2.0** (2023-10-28): Implemented basic web interface for real-time depth viewing.
-   **0.2.1** (2023-10-29): Corrected potentiometer range and temporarily disabled OLED.
-   **0.2.2** (2023-10-30): Updated potentiometer specifications and theoretical precision.
-   **0.3.0** (2023-11-01): Migrated to ESP32-C6 with 1.47-inch ST7789 TFT LCD.
-   **0.4.0** (2023-11-02): Switched to ESP-IDF framework and updated pinout for Waveshare board.

## Technical Stack

-   **Microcontroller:** ESP32-C6
-   **Development Environment:** PlatformIO (VS Code)
-   **Programming Language:** C (ESP-IDF), HTML, CSS, JavaScript
-   **Framework:** Espressif IoT Development Framework (ESP-IDF)
-   **Libraries (Initial ESP-IDF):**
    -   `driver/gpio`
    -   `driver/spi_master`
    -   `esp_log`
    -   `freertos/FreeRTOS`
    -   `freertos/task`
    -   (Further libraries for Wi-Fi, HTTP server, WebSockets, display graphics like LVGL will be added as needed)
-   **Hardware:**
    -   **Waveshare ESP32-C6-LCD-1.47** development board (with integrated ST7789 TFT LCD)
    -   10k Slide Potentiometer (60mm travel, Bourns PTA6043-2015DPB103)
    -   Push Buttons (x4)
    -   Onboard WS2812 RGB LED

## Notes

-   Theoretical precision of 0.0146 mm over 60mm with a 10k potentiometer and ESP32's 12-bit ADC is achievable. Calibration and noise reduction techniques will be crucial for practical accuracy.
-   Consider power supply for the potentiometer to ensure stable readings.
-   The `data` folder for SPIFFS content needs to be uploaded using PlatformIO's "Upload File System Image" command.
-   **IMPORTANT:** The current `src/main.cpp` is a minimal ESP-IDF example for display initialization. Migrating the full application logic (Wi-Fi, WebSockets, JSON parsing, sensor reading, button handling, FastLED, etc.) from the Arduino framework to ESP-IDF's native APIs is a significant undertaking and will require substantial development.

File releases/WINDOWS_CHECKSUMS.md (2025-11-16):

# Generating Checksums on Windows

Windows doesn't have `md5sum` or `sha256sum` commands like Linux. Instead, use **PowerShell**.

---

## Method 1: PowerShell Commands (Manual)

### Open PowerShell

1. Press `Win + X`
2. Select **Windows PowerShell** or **Terminal**
3. Navigate to firmware directory:
   ```powershell
   cd releases\v1.0\
   ```

### Generate MD5 Checksums

```powershell
Get-FileHash -Path firmware.bin -Algorithm MD5
Get-FileHash -Path spiffs.bin -Algorithm MD5
Get-FileHash -Path bootloader.bin -Algorithm MD5
Get-FileHash -Path partitions.bin -Algorithm MD5
```

**Output example**:
```
Algorithm       Hash                                                                   Path
---------       ----                                                                   ----
MD5             A1B2C3D4E5F6G7H8I9J0K1L2M3N4O5P6                                       C:\...\firmware.bin
```

### Generate SHA256 Checksums

```powershell
Get-FileHash -Path firmware.bin -Algorithm SHA256
Get-FileHash -Path spiffs.bin -Algorithm SHA256
Get-FileHash -Path bootloader.bin -Algorithm SHA256
Get-FileHash -Path partitions.bin -Algorithm SHA256
```

### Get File Sizes

```powershell
Get-Item firmware.bin | Select-Object Name, Length
Get-Item spiffs.bin | Select-Object Name, Length
Get-Item bootloader.bin | Select-Object Name, Length
Get-Item partitions.bin | Select-Object Name, Length
```

---

## Method 2: PowerShell Script (Automated)

We've provided a script that generates all checksums automatically!

### Usage

1. **Copy binaries** to `releases/v1.0/`:
   ```powershell
   Copy-Item .pio\build\esp32c6_touch\*.bin releases\v1.0\
   ```

2. **Navigate** to releases directory:
   ```powershell
   cd releases\v1.0\
   ```

3. **Run script**:
   ```powershell
   .\generate_checksums.ps1
   ```

4. **Output**: Creates `CHECKSUMS.md` with all hashes and file sizes

### Script Output Example

```markdown
# PowderSense v1.0 - Firmware Checksums

Generated: 2025-11-10 15:30:00

## bootloader.bin

- **Size**: 24576 bytes (24.00 KB / 0.02 MB)
- **MD5**: `A1B2C3D4E5F6G7H8I9J0K1L2M3N4O5P6`
- **SHA256**: `1234567890ABCDEF1234567890ABCDEF1234567890ABCDEF1234567890ABCDEF`

## partitions.bin

- **Size**: 3072 bytes (3.00 KB / 0.00 MB)
- **MD5**: `X1Y2Z3A4B5C6D7E8F9G0H1I2J3K4L5M6`
- **SHA256**: `FEDCBA0987654321FEDCBA0987654321FEDCBA0987654321FEDCBA0987654321`

## firmware.bin

- **Size**: 1234567 bytes (1205.63 KB / 1.18 MB)
- **MD5**: `M1N2O3P4Q5R6S7T8U9V0W1X2Y3Z4A5B6`
- **SHA256**: `ABCDEF1234567890ABCDEF1234567890ABCDEF1234567890ABCDEF1234567890`

## spiffs.bin

- **Size**: 1572864 bytes (1536.00 KB / 1.50 MB)
- **MD5**: `C1D2E3F4G5H6I7J8K9L0M1N2O3P4Q5R6`
- **SHA256**: `1234567890ABCDEF1234567890ABCDEF1234567890ABCDEF1234567890ABCDEF`
```

---

## Method 3: Third-Party Tools (Optional)

### HashTab (Windows Explorer Integration)

1. Download: http://implbits.com/products/hashtab/
2. Install (adds "File Hashes" tab to Properties)
3. Right-click file → Properties → File Hashes tab
4. See MD5, SHA256, and other hashes

### certutil (Built-in Windows Tool)

```cmd
certutil -hashfile firmware.bin MD5
certutil -hashfile firmware.bin SHA256
```

**Note**: Output format is different (multi-line)

---

## Quick Reference Card

| Task | PowerShell Command |
|---|---|
| MD5 hash | `Get-FileHash file.bin -Algorithm MD5` |
| SHA256 hash | `Get-FileHash file.bin -Algorithm SHA256` |
| File size | `(Get-Item file.bin).Length` |
| All files | `Get-ChildItem *.bin \| Get-FileHash -Algorithm MD5` |
| Copy hash only | `(Get-FileHash file.bin -Algorithm MD5).Hash` |

---

## Verifying Downloads (For Users)

Users can verify downloaded firmware:

```powershell
# Download firmware
# Then verify:
Get-FileHash -Path firmware.bin -Algorithm SHA256

# Compare output with published checksum in README.md
```

**If hashes match**: File is authentic and not corrupted ✅  
**If hashes differ**: File is corrupted or tampered ❌

---

## Why Checksums Matter

✅ **Integrity**: Verify files weren't corrupted during download  
✅ **Authenticity**: Confirm files are from official source  
✅ **Debugging**: Ensure correct firmware version is flashed  
✅ **Transparency**: Open source best practice

---

*Windows Checksums Guide by Processware - November 2025*  
*Part of the PowderSense Open Source Project*

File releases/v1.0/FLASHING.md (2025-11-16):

# PowderSense v1.0 - Pre-Built Firmware Flashing Guide

This directory contains pre-built firmware binaries for PowderSense v1.0, allowing you to flash the device without compiling from source.

---

## 📦 What's Included

### Required Files (for flashing)

| File | Size | Description | Flash Address |
|---|---|---|---|
| `bootloader.bin` | ~24KB | ESP32-C6 bootloader | 0x0000 |
| `partitions.bin` | ~3KB | Partition table | 0x8000 |
| `firmware.bin` | ~1.2MB | Main application firmware | 0x10000 |
| `spiffs.bin` | ~1.5MB | Web interface files (HTML/CSS/JS) | 0x290000 |

**Important Notes**:
- **Waveshare boards come with bootloader and partitions pre-flashed**
- For **updates**: You only need `firmware.bin` and `spiffs.bin`
- For **first-time** or **after erase**: You need all 4 files

### Optional Files (for reference)

| File | Description |
|---|---|
| `firmware.elf` | Debug symbols (not needed for flashing) |
| `firmware.map` | Memory map (not needed for flashing) |

---

## 🔧 Flashing Methods

### Method 1: Using esptool.py (Recommended)

**Prerequisites**:
```bash
pip install esptool
```

**Flash Command** (all-in-one):
```bash
esptool.py --chip esp32c6 --port COM3 --baud 921600 \
  --before default_reset --after hard_reset write_flash \
  -z --flash_mode dio --flash_freq 80m --flash_size 4MB \
  0x0000 bootloader.bin \
  0x8000 partitions.bin \
  0x10000 firmware.bin \
  0x290000 spiffs.bin
```

**Note**: Replace `COM3` with your actual port:
- **Windows**: `COM3`, `COM4`, etc. (check Device Manager)
- **Linux**: `/dev/ttyUSB0`, `/dev/ttyACM0`
- **macOS**: `/dev/cu.usbserial-*`

**Simplified Flash** (firmware + spiffs only):
```bash
# Flash firmware
esptool.py --chip esp32c6 --port COM3 write_flash 0x10000 firmware.bin

# Flash web interface
esptool.py --chip esp32c6 --port COM3 write_flash 0x290000 spiffs.bin
```

---

### Method 2: Using ESP Flash Download Tool (Windows GUI)

**Download**: [ESP Flash Download Tool](https://www.espressif.com/en/support/download/other-tools)

**Steps**:
1. Open ESP Flash Download Tool
2. Select **ESP32-C6**
3. Configure flash settings:
   - **SPI SPEED**: 80MHz
   - **SPI MODE**: DIO
   - **FLASH SIZE**: 4MB
4. Add files with addresses:
   - `bootloader.bin` @ `0x0000`
   - `partitions.bin` @ `0x8000`
   - `firmware.bin` @ `0x10000`
   - `spiffs.bin` @ `0x290000`
5. Select COM port
6. Click **START**

---

### Method 3: Using PlatformIO (if you have VS Code)

**If you have PlatformIO installed but don't want to compile**:

1. Copy `firmware.bin` to `.pio/build/esp32c6_touch/`
2. Copy `spiffs.bin` to `.pio/build/esp32c6_touch/`
3. In PlatformIO:
   - Click **Upload** (uploads firmware)
   - Click **Upload Filesystem Image** (uploads spiffs)

---

## 📍 Memory Addresses (ESP32-C6)

| Component | Address | Size | Description |
|---|---|---|---|
| Bootloader | 0x0000 | ~24KB | ESP32-C6 bootloader |
| Partition Table | 0x8000 | 3KB | Partition layout |
| NVS | 0x9000 | 20KB | Non-volatile storage |
| OTA Data | 0xE000 | 8KB | OTA update metadata |
| **Firmware** | **0x10000** | ~1.2MB | **Main application** |
| **SPIFFS** | **0x290000** | ~1.5MB | **Web interface files** |

---

## ⚠️ Troubleshooting

### "Failed to connect"
- Hold **BOOT** button while connecting USB
- Try lower baud rate: `--baud 115200`
- Check USB cable (must support data, not just charging)
- Install CH340/CP2102 drivers if needed

### "Invalid head of packet"
- Wrong chip type selected (ensure ESP32-C6)
- Corrupted binary file (re-download)
- Bad USB connection

### "Flash will be erased"
- Normal! This erases old firmware before writing new
- Your WiFi credentials will be preserved (stored in NVS)

### "A fatal error occurred"
- Check COM port is correct
- Close other programs using serial port (Arduino IDE, PuTTY, etc.)
- Try different USB port

---

## 🔄 Updating Firmware

**To update to a newer version**:
1. Download new `firmware.bin` and `spiffs.bin`
2. Flash using same commands as above
3. Device will reboot automatically
4. WiFi credentials and calibration data are preserved

**To do a clean install** (erase everything):
```bash
# Erase entire flash
esptool.py --chip esp32c6 --port COM3 erase_flash

# Then flash firmware + spiffs
esptool.py --chip esp32c6 --port COM3 write_flash 0x10000 firmware.bin
esptool.py --chip esp32c6 --port COM3 write_flash 0x290000 spiffs.bin
```

---

## ✅ Verification

After flashing:
1. Open serial monitor (115200 baud)
2. Press **RESET** button on device
3. You should see boot messages
4. Device creates WiFi AP: "PowderSense-XXXX"
5. Connect and configure WiFi

---

## 📝 Build Information

- **Version**: 1.0
- **Build Date**: November 2025
- **Chip**: ESP32-C6
- **Board**: Waveshare ESP32-C6 1.47" LCD
- **Framework**: Arduino (ESP-IDF)
- **Compiler**: GCC 11.2.0

---

## 🆘 Support

**Issues with flashing?**
- GitHub Issues: https://github.com/me-processware/powdersense/issues
- Email: info@processware.nl

**Want to compile from source instead?**
- See main README.md for build instructions
- Requires PlatformIO and Visual Studio Code

---

*Pre-built binaries by Processware - November 2025*  
*Part of the PowderSense Open Source Project*

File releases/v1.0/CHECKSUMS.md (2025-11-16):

# PowderSense v1.0 - Firmware Checksums

**Generated**: November 10, 2025  
**Build Date**: November 2025  
**Version**: 1.0

---

## bootloader.bin

- **Size**: 20,672 bytes (20.2 KB)
- **Flash Address**: 0x0000
- **MD5**: `9985e72399d371ee61de7c4d1d669485`
- **SHA256**: `a57485bef96b7be694204427b70d920263f076a352956cb0e36b9ffce0fa12a8`

---

## partitions.bin

- **Size**: 3,072 bytes (3.0 KB)
- **Flash Address**: 0x8000
- **MD5**: `588df43564950cbb0bd3c5fb5c081df0`
- **SHA256**: `5233eab607f53cb0d175f13f25cf917e5496e340e2565188cf9550b4080c449c`

---

## firmware.bin

- **Size**: 1,367,888 bytes (1.3 MB)
- **Flash Address**: 0x10000
- **MD5**: `ba6a9b08752c0f15e5bdd31c9f690724`
- **SHA256**: `f2a37c0f4d5cb3068e576668ed19a5684c8047fa11ae392ddbd338c04efd0115`

---

## spiffs.bin

- **Size**: 983,040 bytes (960 KB)
- **Flash Address**: 0x290000
- **MD5**: `10b9ae4c20b10dfc378bfb63925f72f4`
- **SHA256**: `d3db9c5fb5bb24c81f5cb9a64315ccbd27517e52b2513ab54a03e943bd2a8304`

---

## Verification

To verify downloaded files on **Windows** (PowerShell):
```powershell
Get-FileHash -Path firmware.bin -Algorithm MD5
Get-FileHash -Path firmware.bin -Algorithm SHA256
```

To verify on **Linux/macOS**:
```bash
md5sum firmware.bin
sha256sum firmware.bin
```

Compare the output with the checksums above. If they match, the file is authentic and not corrupted.

---

## Total Package Size

**All files**: ~2.3 MB

---

*Checksums generated by Processware - November 2025*  
*Part of the PowderSense Open Source Project*

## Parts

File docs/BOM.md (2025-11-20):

# PowderSense - Bill of Materials (BOM)

**Project**: PowderSense Precision Measurement System  
**Designer**: Processware  
**Version**: 1.0  
**Last Updated**: November 2025  
**Currency**: EUR (€)

---

## 📋 Complete Parts List

This document lists all components required to build one complete PowderSense unit. Prices are approximate and may vary based on supplier, quantity, and location.

---

## 🔌 Electronics Components

### Main Components

| # | Component | Specification | Qty | Unit Price | Total | Supplier | Part Number / Link |
|---|---|---|-----|---|---|---|---|
| 1 | **ESP32-C6 Development Board** | 1.47" LCD, Touch version, **NOT soldered** | 1 | €15.00 | €15.00 | AliExpress | [Link](https://nl.aliexpress.com/item/1005007751726345.html) |
| 2 | **ADS1115 ADC Module** | 16-bit, I2C, Low power | 1 | €3.50 | €3.50 | AliExpress | ZY-ADS1115 [Link](https://nl.aliexpress.com/item/1005008882714064.html) |
| 3 | **Slide Potentiometer** | 10kΩ, 60mm travel, Linear | 1 | €12.99 | €12.99 | Conrad | Bourns PTA6043-2015DPB103 [Link](https://www.conrad.nl/nl/p/bourns-schuifpotmeter-10-k-0-25-w-lineair-1-stuk-s-2996439.html) |

**Electronics Subtotal**: €31.49

### Notes on Main Components

**ESP32-C6 Board**:
- ⚠️ **Important**: Order the **NOT soldered** version for easier assembly
- Touch functionality exists but is not enabled in current firmware
- Includes integrated 1.47" ST7789 TFT LCD (172x320 pixels)
- USB-C for programming and power

**ADS1115 Module**:
- Provides 16-bit precision (vs 12-bit internal ESP32 ADC)
- I2C interface (address 0x48 default)
- Programmable gain amplifier (PGA)
- Essential for achieving 0.0146mm theoretical resolution

**Potentiometer**:
- Bourns PTA6043-2015DPB103 is the recommended model
- 60mm travel distance
- ±0.25% linearity
- 1 million cycle mechanical life

![Bourns Slide Potentiometer] with cut legs example: (images/bourns_potentiometer.png)
*Bourns PTA6043-2015DPB103 - 10kΩ 60mm linear slide potentiometer*

---

## ⚙️ Mechanical Components

### Motion System

| # | Component | Specification | Qty | Unit Price | Total | Supplier | Part Number / Link |
|---|---|---|-----|---|---|---|---|
| 4 | **Compression Spring** | 0.9mm wire × 6mm OD × 70mm length | 1 | €1.50 | €1.50 | AliExpress | [Link](https://nl.aliexpress.com/item/1005007124937621.html) | (!! there was an error on the provided bag it stated 0.9x5x70 this is wrong and has to be 0.9x6x70 !!
| 5 | **Slide Bearings** | 4mm bore diameter, igus XFM-0405-04 | 2 | €2.50 | €5.00 | Conrad | igus XFM-0405-04 [Link](https://www.conrad.nl/nl/p/igus-xfm-0405-04-glijlager-boordiameter-4-mm-1416628.html) |
| 6 | **Steel Rod** | 4mm diameter × 500mm length, silver steel | 1 | €4.99 | €4.99 | Conrad | Reely 237060 [Link](https://www.conrad.nl/nl/p/zilverstalen-as-reely-o-x-l-4-mm-x-500-mm-237060.html) |

**Mechanical Subtotal**: €11.49

### Notes on Mechanical Components

**Spring**:
- Provides return force for measurement probe
- 0.9mm wire diameter ensures adequate force without being too stiff
- 70mm length allows for full 60mm travel plus compression

**Slide Bearings**:
- igus polymer bearings are self-lubricating and maintenance-free
- 4mm bore matches steel rod diameter
- Low friction for smooth measurement

**Steel Rod**:
- 500mm length provides material for probe shaft (cut to length)
- Silver steel is precision ground and hardened
- 4mm diameter is standard and readily available
- **Cutting**: Cut to 85mm length with Dremel
- **Threading**: M4 thread on one end (~5mm deep)
- **Grooving**: 6mm groove on other end for potentiometer attachment

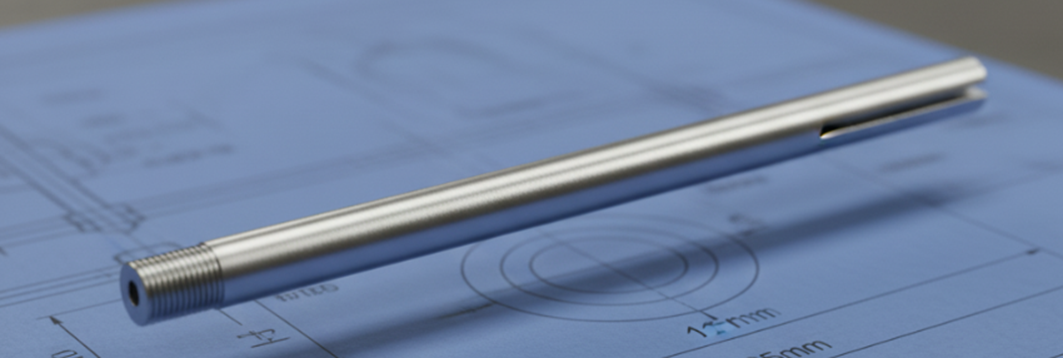
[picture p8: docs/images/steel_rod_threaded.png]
Steel Rod with Threading

*4mm steel rod with M4 threading - ready for assembly*

---

## 🔩 Hardware & Fasteners

### Assembly Hardware

| # | Component | Specification | Qty | Unit Price | Total | Supplier | Notes |
|---|---|---|-----|---|---|---|---|
| 7 | **M3 × 8mm Screws** | Pan head or button head | 4 | €0.10 | €0.40 | Local hardware | Case assembly |
| 8 | **M3 × 6mm Screws** | Pan head | 4 | €0.10 | €0.40 | Local hardware | Display bezel |
| 9 | **M2.5 × 6mm Screws** | Pan head | 4 | €0.10 | €0.40 | Local hardware | PCB mounting |
| 10 | **M3 Heat-Set Inserts** | 4mm OD × 5mm length | 4 | €0.15 | €0.60 | AliExpress/Amazon | Optional, recommended |

**Hardware Subtotal**: €1.80

### Wiring & Connectors

| # | Component | Specification | Qty | Unit Price | Total | Supplier | Notes |
|---|---|---|-----|---|---|---|---|
| 11 | **Dupont Jumper Wires** | Female-Female, 20cm | 10 | €0.05 | €0.50 | AliExpress | Prototyping |
| 12 | **Silicone Wire** | 22-24 AWG, various colors | 2m | €1.00/m | €2.00 | AliExpress | Permanent wiring |
| 13 | **Heat Shrink Tubing** | Assorted sizes | 10 pcs | €0.05 | €0.50 | AliExpress | Wire protection |
| 14 | **USB-C Cable** | 1m, data + power | 1 | €3.00 | €3.00 | Local electronics | Programming/Power |

**Wiring Subtotal**: €6.00

---

## 🖨️ 3D Printed Parts

### Enclosure Components

| # | Component | Material | Qty | Material Used | Est. Cost | Print Time | Notes |
|---|---|---|-----|---|---|---|---|
| 15 | **Complete Enclosure** | PETG or PLA | 1 set | ~130-150g | €3.00-5.00 | 6-8 hours | See `hardware/enclosure/` |

**3D Printing Subtotal**: €4.00 (average)

### Notes on 3D Printing

**Material Recommendations**:
- **PETG** (preferred): Better temperature resistance, durability
- **PLA**: Easier to print, adequate for indoor use
- **Not recommended**: ABS (warping, fumes)

**Filament Cost Calculation**:
- PETG: ~€20/kg → 150g = €3.00
- PLA: ~€18/kg → 150g = €2.70

**Print Files**:
- Download from `hardware/enclosure/powdersense_main_offset_displayv2.3mf`
- See [hardware/enclosure/README.md](../hardware/enclosure/README.md) for detailed printing instructions

---

## 💰 Cost Summary

### Total Component Cost

| Category | Subtotal |
|---|---|
| Electronics Components | €31.49 |
| Mechanical Components | €11.49 |
| Hardware & Fasteners | €1.80 |
| Wiring & Connectors | €6.00 |
| 3D Printed Parts | €4.00 |
| **TOTAL (per unit)** | **€54.78** |

### Cost Breakdown by Source

| Supplier | Approximate Cost | Shipping | Notes |
|---|---|---|---|
| AliExpress | €20.00 | €0-5 | Electronics, spring, wire |
| Conrad.nl | €22.98 | €5.95 | Potentiometer, bearings, rod |
| Local Hardware | €2.20 | €0 | Screws and fasteners |
| 3D Printing | €4.00 | €0 | Self-printed |
| **TOTAL** | **€49.18** | **€5.95** | **€55.13 including shipping** |

## 🛒 Purchasing Guide

### Recommended Order Strategy

**Option 1: All-in-One (Fastest)**
- Order all AliExpress items in one order (combined shipping)
- Order Conrad items separately (faster EU shipping)
- Local hardware from nearby store

**Option 2: Budget-Focused (Cheapest)**
- Wait for AliExpress sales (11.11, Black Friday)
- Order larger quantities for discounts
- Source alternatives from local suppliers

**Option 3: Quick Start (Fastest Build)**
- Order only Conrad items first (2-3 day delivery)
- Use temporary wiring while waiting for AliExpress
- 3D print enclosure while waiting

### Lead Times

| Supplier | Typical Delivery | Express Option |
|---|---|---|
| AliExpress | 2-4 weeks | 1-2 weeks (+€5-10) |
| Conrad.nl | 2-3 days | Next day (+€7.95) |
| Local Hardware | Same day | N/A |

---

## 🔄 Alternative Components

### Budget Alternatives

**Lower Cost Options** (saves ~€10):

| Original | Alternative | Savings | Trade-off |
|---|---|---|---|
| Bourns potentiometer | Generic 10kΩ slide pot | €8 | Lower quality, less precise |
| igus bearings | Bronze bushings | €3 | More friction, needs lubrication |
| PETG filament | PLA filament | €1 | Less durable |

**Total with alternatives**: ~€45/unit

### Premium Alternatives

**Higher Quality Options** (adds ~€15):

| Original | Alternative | Cost | Benefit |
|---|---|---|---|
| Generic spring | Precision compression spring | +€3 | More consistent force |
| Steel rod | Hardened ground shaft | +€5 | Better precision, corrosion resistant |
| Standard wire | Shielded cable | +€5 | Better noise immunity |
| Standard screws | Stainless steel hardware | +€2 | Corrosion resistant |

**Total with premium parts**: ~€70/unit

### Sensor Alternatives

**Different Measurement Methods**:

| Sensor Type | Cost | Pros | Cons |
|---|---|---|---|
| **10kΩ Potentiometer** (current) | €13 | Simple, reliable | Contact wear |
| Magnetic linear encoder | €25-40 | Non-contact, precise | More complex wiring |
| Ultrasonic distance sensor | €5-10 | Non-contact, cheap | Lower precision |
| Laser ToF sensor | €15-30 | Very precise | Requires clear line of sight |

---

## 🔧 Tools Required

### Essential Tools

| Tool | Purpose | Approximate Cost |
|---|---|---|
| Soldering iron | Wire connections | €20-50 |
| Wire strippers | Wire preparation | €10-15 |
| Flush cutters | Trimming wires/rods | €8-12 |
| Small screwdrivers | Assembly | €10-15 |
| Multimeter | Testing/debugging | €15-30 |
| 3D Printer | Enclosure printing | €200-500 (or use service) |

**Total tool investment**: €263-622 (one-time)

### Optional Tools

| Tool | Purpose | Approximate Cost |
|---|---|---|
| Heat gun | Heat shrink tubing | €15-25 |
| Helping hands | Soldering assistance | €10-15 |
| Drill + bits | Modifying enclosure | €30-50 |
| Calipers | Measuring/verification | €15-30 |
| Hacksaw | Cutting steel rod | €10-15 |

---

## 🌍 International Sourcing

### Regional Suppliers

**Europe (EU)**:
- **Electronics**: Mouser, DigiKey, Farnell
- **Mechanical**: RS Components, Conrad
- **3D Printing**: Local maker spaces or online services

**North America (US/CA)**:
- **Electronics**: DigiKey, Mouser, Adafruit, SparkFun
- **Mechanical**: McMaster-Carr, Grainger
- **3D Printing**: Shapeways, Craftcloud

**Asia-Pacific (AU/NZ)**:
- **Electronics**: Element14, Jaycar
- **Mechanical**: RS Components AU
- **General**: AliExpress (long shipping)

### Import Considerations

**Ordering from China (AliExpress)**:
- **Duties/VAT**: Orders >€22 may incur import fees (EU)
- **Shipping time**: 2-4 weeks standard, 1-2 weeks express
- **Quality**: Check seller ratings and reviews
- **Warranty**: Limited or none, order spares

---

## ✅ Quality Control Checklist

### Incoming Inspection (for each component)

**Electronics**:
- [ ] ESP32-C6 board: Check for physical damage, test boot
- [ ] ADS1115: Verify I2C address, test with multimeter
- [ ] Potentiometer: Check resistance, smooth travel

**Mechanical**:
- [ ] Spring: Verify dimensions, test compression
- [ ] Bearings: Check fit on rod, smooth movement
- [ ] Steel rod: Verify diameter (4.00mm ±0.05mm), straightness

**3D Printed Parts**:
- [ ] No warping or layer separation
- [ ] Holes are clear and correct size
- [ ] Surfaces are smooth (no major defects)

### Pre-Assembly Testing

- [ ] Test ESP32-C6 board (upload test firmware)
- [ ] Verify ADS1115 communication (I2C scan)
- [ ] Measure potentiometer resistance (should be 10kΩ ±5%)
- [ ] Test display functionality

---

## 📝 Notes & Tips

### Sourcing Tips

**AliExpress**:
- Look for "Choice" or "Plus" items (faster shipping, better quality)
- Check seller ratings (>95% positive, >1000 orders)
- Read reviews for actual product quality
- Order 10-20% extra for spares/defects

**Conrad**:
- Watch for sales and promotions
- Consider business account for discounts
- Free shipping on orders >€50 (NL)

**Local Hardware**:
- Buy assortment packs of screws (cheaper per unit)
- Stainless steel recommended for longevity

### Cost Optimization

**For Prototyping** (1-5 units):
- Accept longer AliExpress shipping
- Use generic components where possible
- 3D print yourself

**For Small Production** (10-50 units):
- Bulk order from AliExpress (negotiate with seller)
- Consider PCB assembly service (JLCPCB, PCBWay)
- Outsource 3D printing for consistency

**For Scaling** (50+ units):
- Direct sourcing from manufacturers
- Custom PCB with integrated components
- Injection molded enclosure (requires tooling investment)

---

## 🔗 Quick Links

### Supplier Websites

- **AliExpress**: https://www.aliexpress.com
- **Conrad NL**: https://www.conrad.nl
- **Mouser**: https://www.mouser.com
- **DigiKey**: https://www.digikey.com
- **RS Components**: https://nl.rs-online.com

### Datasheets

- **ESP32-C6**: [Espressif Documentation](https://www.espressif.com/en/products/socs/esp32-c6)
- **ADS1115**: [Texas Instruments Datasheet](https://www.ti.com/product/ADS1115)
- **Bourns PTA6043**: [Bourns Datasheet](https://www.bourns.com/products/potentiometers/slide-potentiometers)

---

## 📞 Support

**Questions about components or sourcing?**

- **GitHub Issues**: Component questions or alternatives
- **GitHub Discussions**: Sourcing tips and recommendations
- **Email**: info@processware.nl

**Found a better source or alternative?** Please share in GitHub Discussions 

## 📄 License

This Bill of Materials is part of the PowderSense project and is licensed under **CC BY-SA 4.0**.

You are free to use, modify, and share this BOM, provided you:
- Give attribution to Processware
- Share modifications under the same license

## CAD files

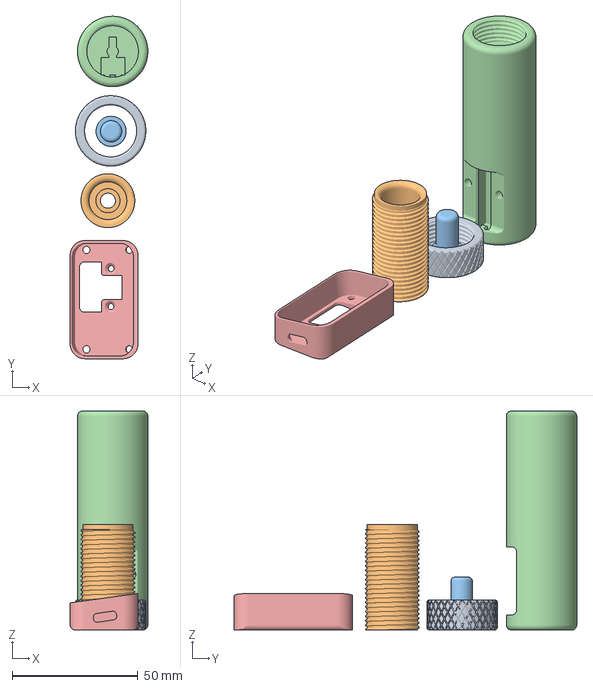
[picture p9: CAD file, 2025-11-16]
hardware/enclosure/powdersense_complete_v1.3mf
30.9 x 136.1 x 87.0 mm

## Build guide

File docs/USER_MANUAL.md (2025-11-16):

# PowderSense - User Manual

**Product**: PowderSense Precision Measurement System  
**Author**: Processware  
**Version**: 1.0  
**Last Updated**: November 2025

---

## 📖 Table of Contents

1. [Introduction](#introduction)
2. [Quick Start Guide](#quick-start-guide)
3. [Device Overview](#device-overview)
4. [Display States](#display-states)
5. [First Time Setup](#first-time-setup)
6. [Web Interface](#web-interface)
7. [Configuration & Calibration](#configuration--calibration)
8. [Using PowderSense](#using-powdersense)
9. [Troubleshooting](#troubleshooting)
10. [Maintenance & Safety](#maintenance--safety)

---

## 🎯 Introduction

### What is PowderSense?

PowderSense is a precision measurement system designed for ammunition reloading. It measures powder depth with high precision and converts it to grain weight for consistent ammunition loading. The device features a 1.47" color display for status monitoring and a WiFi-enabled web interface for complete control and configuration.

### Key Features

- **High Precision**: 16-bit ADC (ADS1115) with 0.001 grain display precision
- **60mm Measurement Range**: Suitable for most reloading applications
- **WiFi Control**: Complete web interface for configuration and monitoring
- **Visual Feedback**: Color-coded display shows measurement status
- **Auto-Measurement**: Automatic detection of stable measurements
- **Data Logging**: Session tracking with CSV export
- **Multiple Profiles**: Store different powder configurations

### Technical Specifications

| Parameter | Value |
|---|---|
| **Measurement Range** | 0-60mm |
| **Display Precision** | 0.001 grain |
| **Accuracy** | ±0.1mm (after calibration) |
| **Sampling Rate** | 10 Hz |
| **Display** | 1.47" TFT LCD (172×320 pixels) |
| **Connectivity** | WiFi 802.11 b/g/n |
| **Power** | 5V DC via USB-C |
| **Power Consumption** | <2W |

---

## 🚀 Quick Start Guide

### What You Need

- PowderSense device (assembled)
- USB-C cable and 5V power adapter
- Computer or smartphone with WiFi
- Web browser (Chrome, Firefox, Safari, Edge)
- Precision scale for calibration

### 5-Minute Setup

**Step 1: Power On**
1. Connect USB-C cable to PowderSense and power adapter
2. Device boots and shows splash screen
3. Display shows AP Mode screen with WiFi credentials

**Step 2: Connect to WiFi**
1. On your phone/computer, connect to WiFi: **"PowderSense-XXXX"**
2. Password: **"powdersense"**
3. Browser opens automatically (or navigate to **http://192.168.4.1**)
4. Enter your home WiFi credentials and click "Save"
5. Device reboots and connects to your network

**Step 3: Access Web Interface**
1. Display shows your network's IP address (e.g., 192.168.1.100)
2. Open browser and navigate to that IP address
3. Web dashboard loads

**Step 4: Create Configuration**
1. Click **"Add New"** in Quick Settings
2. Enter: Caliber (9mm), Bullet Weight (145gr), Powder (N340), Target (4.7gr)
3. Set Low/High thresholds (e.g., 4.6 - 4.8 grains)
4. Click **"Save Configuration"**

**Step 5: Calibrate**
1. Click **"Calibrate"** button (orange)
2. **Step 1**: Extend probe fully, click "Set Zero"
3. **Step 2**: Insert case with precisely weighed powder (e.g., 4.7 grains)
4. Enter exact weight, click "Set Known Grains"
5. Calibration complete! Status shows "Calibrated" in green

**Step 6: Start Measuring**
1. Place powder measure under probe
2. Adjust powder level
3. Display shows real-time measurement
4. When stable, measurement is automatically recorded

**You're ready to reload!** 🎉

---

## 🖥️ Device Overview

### Physical Components

**Front Panel**:
- **1.47" TFT Display**: Shows current measurement and status (read-only, no touch)
- **Visual Indicators**: Color-coded background (blue/green/red) for measurement status

**Top/Side**:
- **Measurement Probe**: Spring-loaded probe that extends/retracts
- **9mm Probe Tip**: Measures powder depth in cartridge case

**Back Panel**:
- **USB-C Port**: Power input (5V) and firmware updates

**Internal Components**:
- **ESP32-C6**: Main controller with WiFi
- **ADS1115**: 16-bit ADC for precision measurement
- **Potentiometer**: Linear position sensor connected to probe

### Control Method

**Important**: The display is **read-only** and shows status information only. All configuration, calibration, and control is done through the **web interface** accessed via WiFi from your computer or smartphone.

---

## 📺 Display States

The PowderSense display shows different screens depending on the device status. The display is read-only and provides visual feedback only.

### 1. AP Mode (WiFi Setup)

AP Mode Display

**When shown**: First boot or when no WiFi is configured

**Information displayed**:
- "AP MODE ACTIVE"
- WiFi network name: "PowderSense-XXXX"
- Password: "powdersense"
- IP address: http://192.168.4.1

**What to do**: Connect to the displayed WiFi network and configure your home WiFi via the web interface.

---

### 2. No Configuration

No Configuration Display

**When shown**: Device is connected to WiFi but no powder configuration is loaded

**Information displayed**:
- Current measurement: 0.000 grain
- Status: "No Config"
- IP address for web access

**What to do**: Access the web interface and create a powder configuration profile.

---

### 3. Measurement - LOW (Below Target)

Measurement Low Display

**When shown**: Measurement is below target weight

**Information displayed**:
- Current measurement: 4.585 grain
- Target weight: 4.700 grain
- Configuration: 9mm 145gr N340
- **Blue bar**: Indicates below target

**Meaning**: Add more powder to reach target weight.

---

### 4. Measurement - PERFECT (On Target)

Measurement Perfect Display

**When shown**: Measurement is within tolerance of target weight

**Information displayed**:
- Current measurement: 4.700 grain
- Target weight: 4.700 grain
- Configuration: 9mm 145gr N340
- **Green bar**: Indicates perfect measurement

**Meaning**: Powder charge is correct, proceed with loading.

---

### 5. Measurement - HIGH (Above Target)

Measurement High Display

**When shown**: Measurement is above target weight

**Information displayed**:
- Current measurement: 4.802 grain
- Target weight: 4.700 grain
- Configuration: 9mm 145gr N340
- **Red bar**: Indicates above target (alarm)

**Meaning**: Remove powder to reach target weight. Red indicates out-of-spec condition.

---

## 🔧 First Time Setup

### Initial Power-On

When you first power on PowderSense:

1. **Self-Test**: Device performs hardware initialization
2. **Display Check**: Shows PowderSense splash screen
3. **WiFi Check**: Looks for saved WiFi credentials
4. **AP Mode**: If no WiFi configured, starts Access Point mode

### WiFi Configuration

**Connect to PowderSense AP**:
1. Look at display for network name (e.g., "PowderSense-A1B2")
2. On your device, connect to that WiFi network
3. Password: **powdersense**
4. Captive portal should open automatically
5. If not, navigate to: **http://192.168.4.1**

**Configure Home WiFi**:
1. Select your WiFi network from dropdown (or enter manually)
2. Enter your WiFi password
3. Click **"Save Configuration"**
4. Device reboots and connects to your network
5. Display shows new IP address

**Finding Your Device**:
- IP address is shown on the display
- Check your router's DHCP client list
- Use network scanner app (e.g., Fing, Advanced IP Scanner)

**Bookmark the IP address** in your browser for easy access!

---

## 📱 Web Interface

The web interface provides complete control over PowderSense. Access it by navigating to the IP address shown on the display.

### Dashboard

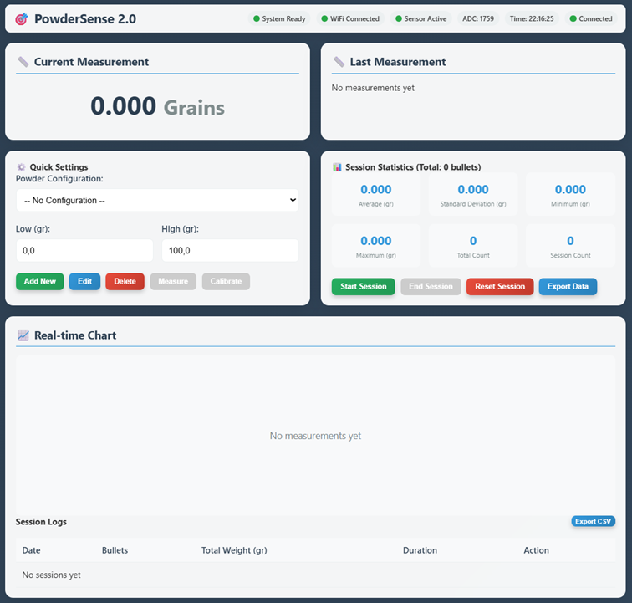
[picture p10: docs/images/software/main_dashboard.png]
Main Dashboard


The main dashboard shows:

**Current Measurement Panel**:
- Large display of current weight in grains
- Updates in real-time (10 times per second)

**Last Measurement Panel**:
- Details of the last recorded measurement
- Timestamp and weight

**Quick Settings Panel**:
- Powder Configuration dropdown
- Low/High grain thresholds
- Buttons: Add New, Edit, Delete, Measure, Calibrate

**Session Statistics Panel**:
- Average, Standard Deviation, Minimum, Maximum
- Total Count, Session Count
- Buttons: Start Session, End Session, Reset Session, Export Data

**Real-time Chart**:
- Visual representation of measurements over time
- Shows last 100 measurements

**Session Logs Table**:
- Historical session data
- Date, bullet count, total weight, duration

---

## 🎯 Configuration & Calibration

### Creating a Configuration Profile

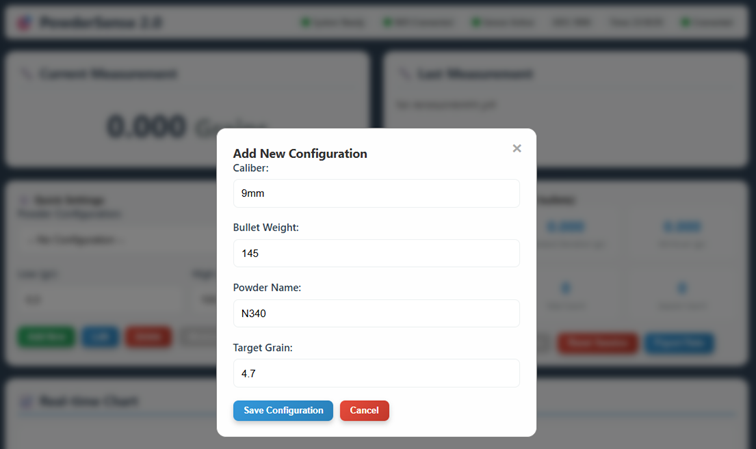
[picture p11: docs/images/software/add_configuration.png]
Add Configuration


A configuration profile stores settings for a specific load:

1. Click **"Add New"** in Quick Settings panel
2. Fill in the dialog:
   - **Caliber**: Cartridge type (e.g., "9mm")
   - **Bullet Weight**: Projectile weight (e.g., "145")
   - **Powder Name**: Powder type (e.g., "N340")
   - **Target Grain**: Desired powder charge (e.g., "4.7")
3. Click **"Save Configuration"**

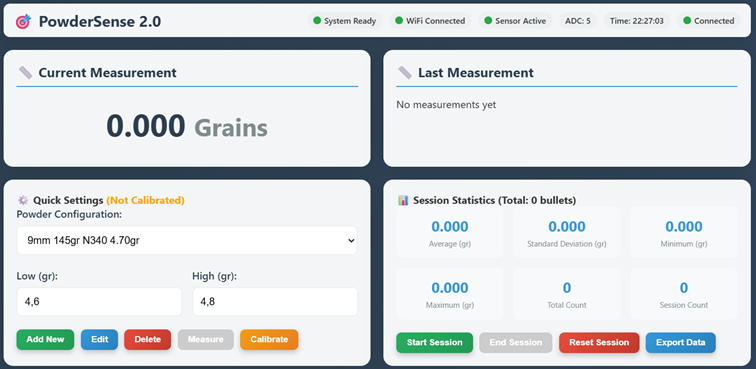
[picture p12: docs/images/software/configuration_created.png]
Configuration Created


The configuration is now active but shows **"Not Calibrated"** in orange. You must calibrate before use.

### Calibration Process

**Why Calibrate?**

Each configuration must be calibrated because:
- Different powders have different densities
- Mechanical tolerances vary
- Temperature affects measurements
- Ensures accurate grain weight readings

**When to Calibrate**:
- After creating a new configuration
- When switching powder types
- If measurements seem inaccurate
- Weekly for frequent use, monthly for occasional use

**Calibration Steps**:

#### Step 1: Set Zero Point

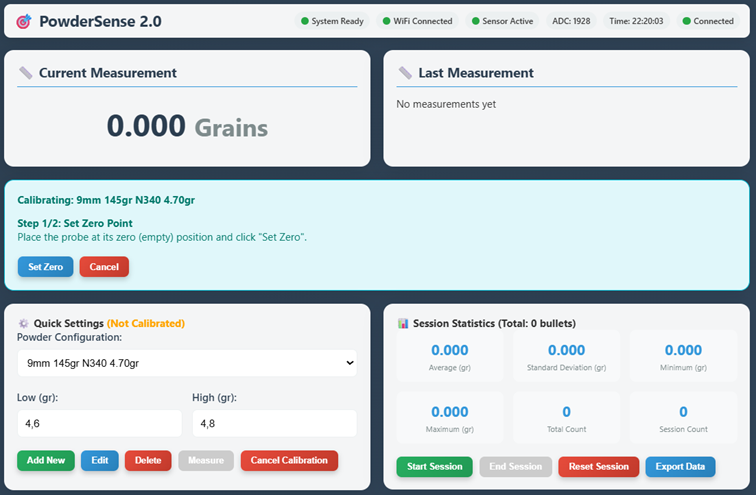
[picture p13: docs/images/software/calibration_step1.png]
Calibration Step 1


1. Click **"Calibrate"** button (orange)
2. Calibration wizard appears
3. **Fully extend the probe** (no compression)
4. Wait for reading to stabilize
5. Click **"Set Zero"** button
6. Confirmation: "Zero point set successfully"

#### Step 2: Set Known Reference

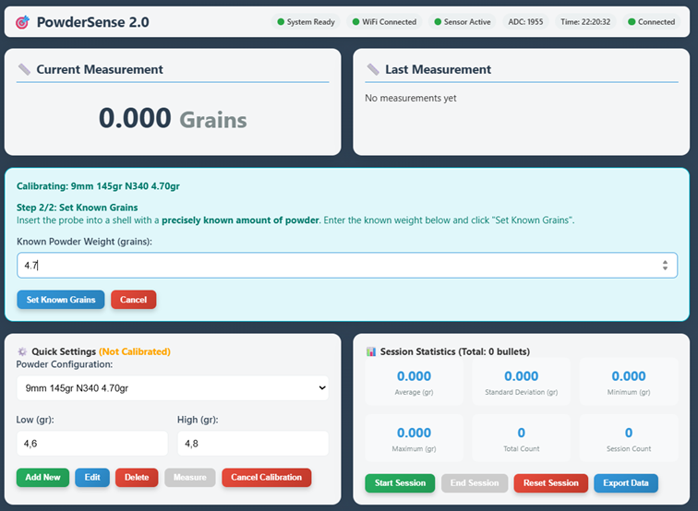
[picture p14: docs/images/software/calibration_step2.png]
Calibration Step 2


1. **Weigh powder precisely** on a scale (e.g., 4.7 grains)
2. **Place powder in case** and position under probe
3. **Insert probe** to measure depth
4. Wait for reading to stabilize (2-3 seconds)
5. **Enter exact weight** in "Known Powder Weight" field
6. Click **"Set Known Grains"** button
7. Device calculates conversion factor
8. Confirmation: "Calibration complete"

**Calibration Tips**:
- Use a precision scale for reference weight
- Use mid-range weight (not too light or heavy)
- Ensure stable environment (no vibration)
- Allow device to warm up (2-3 minutes)
- Wait for readings to stabilize before clicking buttons

---

## 🔬 Using PowderSense

### Active Measurement

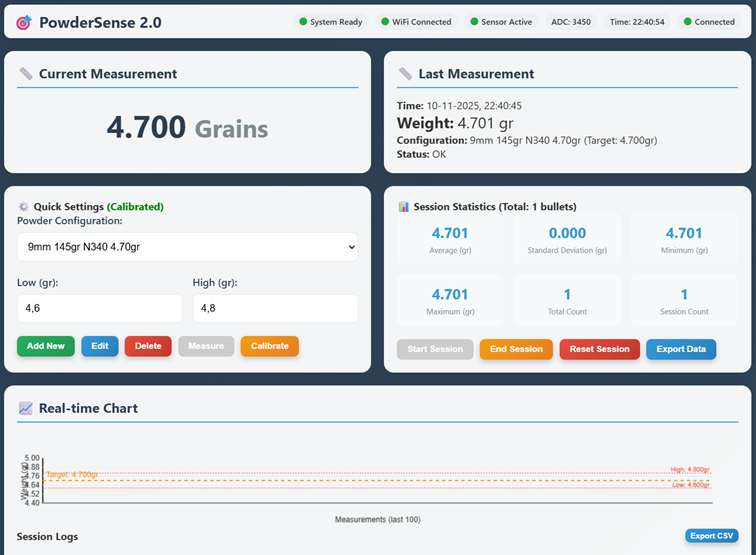
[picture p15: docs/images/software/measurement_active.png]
Active Measurement


Once calibrated, PowderSense is ready to measure:

**Display Shows**:
- Current measurement in real-time
- Last measurement details (timestamp, weight, status)
- Configuration in use (shows "Calibrated" in green)
- Session statistics

**Workflow**:

1. **Dispense Powder**: Use your powder measure to dispense charge
2. **Position Case**: Place case under probe
3. **Insert Probe**: Probe compresses into powder
4. **Read Display**: Check physical display or web interface
5. **Adjust if Needed**: Add or remove powder based on color indicator
6. **Auto-Record**: When stable, measurement is automatically recorded
7. **Next Round**: Remove case and repeat

**Color Indicators**:
- **Blue**: Below target (add powder)
- **Green**: On target (perfect)
- **Red**: Above target (remove powder, alarm)

### Session Tracking

**Starting a Session**:
1. Click **"Start Session"** button
2. Session counter resets to 0
3. Begin measuring rounds

**During Session**:
- Each stable measurement increments counter
- Statistics update in real-time:
  - **Average**: Mean weight
  - **Std Dev**: Consistency indicator (lower is better)
  - **Min/Max**: Range of measurements
  - **Count**: Number of rounds measured

**Ending a Session**:
1. Click **"End Session"** button
2. Session is saved to log with:
   - Date and time
   - Bullet count
   - Total weight
   - Duration
3. Ready to start new session

**Exporting Data**:
- Click **"Export Data"** button
- Downloads CSV file with all measurements
- Open in Excel or Google Sheets for analysis

### Manual vs Auto-Measurement

**Auto-Measurement** (Default):
- System automatically detects stable readings
- When reading is stable for 750ms within ±0.1 grain tolerance, measurement is recorded
- 10-second cooldown prevents duplicate recordings
- Best for production reloading

**Manual Measurement**:
- Click **"Measure"** button to force recording
- Useful for testing or verification
- No automatic detection

---

## 🔧 Troubleshooting

### Display Issues

**Problem**: Display is blank
- Check USB-C power connection
- Try different power adapter (5V, >1A)
- Check for loose ribbon cable inside device

**Problem**: Display shows wrong values
- Perform calibration
- Check that correct configuration is selected
- Restart device (unplug and replug power)

### Measurement Issues

**Problem**: Readings are unstable or jumping
- Check for vibration or movement
- Ensure probe moves smoothly
- Check for mechanical binding
- Recalibrate

**Problem**: Measurements seem inaccurate
- Verify calibration with known weight
- Recalibrate using precision scale
- Check that correct configuration is active
- Ensure probe is fully inserted into powder

**Problem**: Device doesn't detect measurements
- Check auto-measurement settings (stable duration, tolerance)
- Ensure reading is actually stable
- Try manual measurement with "Measure" button

### WiFi Issues

**Problem**: Can't connect to PowderSense AP
- Check display for correct network name
- Verify password: "powdersense" (all lowercase)
- Move closer to device
- Restart device

**Problem**: Device won't connect to home WiFi
- Verify WiFi password is correct
- Check that WiFi is 2.4GHz (device doesn't support 5GHz)
- Ensure WiFi network is not hidden
- Try resetting WiFi configuration

**Problem**: Lost IP address
- Check display (IP is shown on screen)
- Check router DHCP client list
- Use network scanner to find device
- Reset to AP mode if needed

### Calibration Issues

**Problem**: Calibration fails or gives errors
- Ensure probe is stable during zero setting
- Use precise reference weight from scale
- Wait longer for readings to stabilize
- Try recalibrating with different reference weight

**Problem**: Calibration seems incorrect
- Verify reference weight on precision scale
- Use mid-range weight (not extreme low or high)
- Ensure powder is evenly distributed in case
- Check for mechanical issues with probe

---

## 🛠️ Maintenance & Safety

### Regular Maintenance

**Weekly** (for frequent use):
- Clean probe tip with soft brush
- Check probe movement is smooth
- Verify calibration accuracy

**Monthly**:
- Clean display with soft cloth
- Check all connections inside device
- Backup measurement data (export CSV)

**As Needed**:
- Recalibrate when switching powders
- Update firmware when available
- Replace worn components

### Cleaning

**Probe**:
- Use soft brush to remove powder residue
- Do not use solvents or lubricants
- Ensure probe moves freely

**Display**:
- Use soft, lint-free cloth
- Slightly damp if needed
- Do not use harsh chemicals

**Enclosure**:
- Wipe with damp cloth
- Keep away from powder dust
- Ensure ventilation holes are clear

### Safety Information

**Electrical Safety**:
- Use only 5V DC power supply
- Do not expose to water or liquids
- Unplug during cleaning or maintenance
- Do not open device while powered

**Reloading Safety**:
- **Always verify charges with precision scale**
- PowderSense is a measurement aid, not a replacement for safe reloading practices
- Follow published load data
- Never exceed maximum loads
- Use appropriate safety equipment

**Important**: PowderSense measures powder depth and converts to grain weight based on calibration. Accuracy depends on proper calibration and consistent powder density. Always verify critical measurements with a precision scale.

### Firmware Updates

**Checking Version**:
- Current version shown in web interface
- Check GitHub for latest release: https://github.com/me-processware/powdersense

**Updating Firmware**:
- Download latest firmware from GitHub releases
- Follow flashing instructions in releases/v1.0/FLASHING.md
- Requires USB connection and esptool.py or PlatformIO
- Calibration data is preserved during updates

---

## 📞 Support & Resources

### Documentation

- **GitHub Repository**: https://github.com/me-processware/powdersense
- **Assembly Guide**: docs/ASSEMBLY.md
- **Bill of Materials**: docs/BOM.md
- **Flashing Guide**: releases/v1.0/FLASHING.md

### Getting Help

**For Technical Issues**:
- GitHub Issues: Report bugs or problems
- GitHub Discussions: Ask questions, share tips

**For Pre-Built Units**:
- Email: info@processware.nl
- 1 year warranty on assembled units
- Support for setup and calibration

### Community

- Share your builds and modifications
- Contribute improvements via pull requests
- Help other users in GitHub Discussions
- Post photos with #PowderSense

---

**User Manual by Processware - November 2025**  
*Part of the PowderSense Open Source Project*

**Stay Safe. Reload Responsibly.** 🎯

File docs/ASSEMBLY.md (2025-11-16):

# PowderSense - Assembly Guide

**Project**: PowderSense Precision Measurement System  
**Author**: Processware  
**Version**: 1.0  
**Difficulty**: Intermediate  
**Estimated Time**: 2-3 hours  
**Last Updated**: November 2025

---

## ⚠️ Safety First

**Before You Begin**:
- Work in a well-ventilated area (soldering fumes)
- Wear safety glasses when cutting metal
- Use proper tools for each task
- Disconnect power when working on electronics
- Keep a fire extinguisher nearby when soldering

---

## 📋 Prerequisites

### Required Components

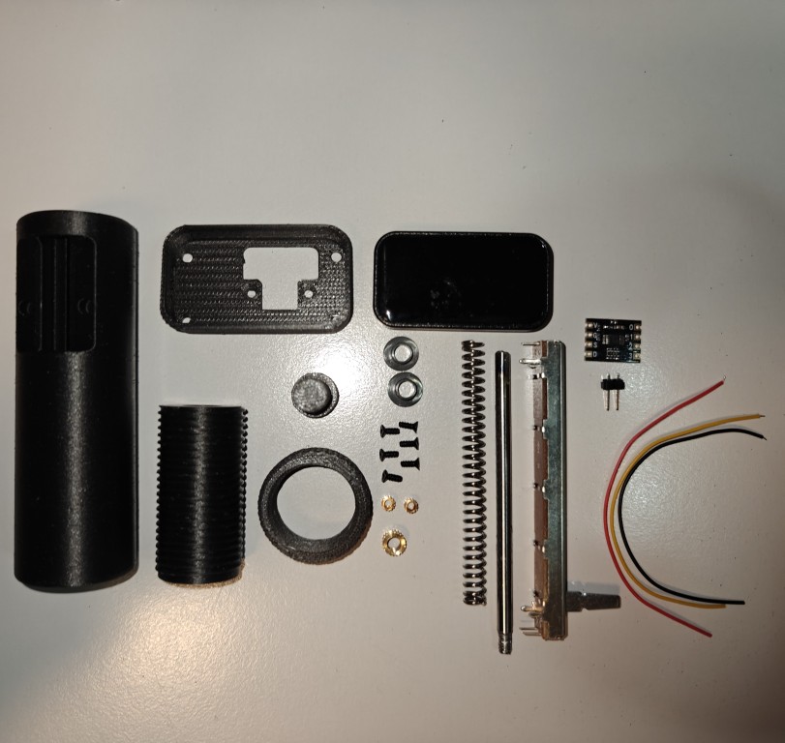
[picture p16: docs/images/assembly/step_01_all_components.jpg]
All Components

*Photo 1: All components laid out and ready for assembly*

Ensure you have all parts from the [Bill of Materials](BOM.md):
- [ ] ESP32-C6 Development Board (1.47" LCD, NOT soldered version)
- [ ] ADS1115 ADC Module
- [ ] Bourns PTA6043-2015DPB103 Slide Potentiometer (10kΩ)
- [ ] Compression Spring (0.9mm × 5mm × 70mm)
- [ ] Slide Bearings (4mm bore, igus XFM-0405-04) × 2
- [ ] Steel Rod (4mm × 500mm)
- [ ] 3D Printed Enclosure (all parts)
- [ ] Hardware (screws, heat-set inserts)
- [ ] Wire and connectors

### Required Tools

**Essential**:
- Soldering iron (temperature controlled, 300-350°C)
- Solder (60/40 or lead-free)
- Wire strippers
- Flush cutters
- Small screwdrivers (Phillips and flat)
- Multimeter
- Rotary tool (Dremel) with cutting disc (1mm)
- M4 tap and tap wrench
- Helping hands or PCB holder
- Heat gun or lighter (for heat-set inserts)

**Recommended**:
- Digital calipers (for measuring)
- Desoldering pump or wick
- Flux pen
- Isopropyl alcohol (cleaning)
- Small files or sandpaper
- Bench vise or clamp

---

## 🔧 Assembly Overview

The build process consists of these main stages:

1. **Preparation**: 3D printed parts post-processing and heat-set inserts
2. **Rod Preparation**: Cutting, threading, and grooving the steel rod
3. **Potentiometer Modification**: Trimming pins and slider
4. **Mechanical Assembly**: Rod, bearings, spring, and probe
5. **Electronics Assembly**: Wiring and soldering connections
6. **Final Assembly**: Installing in enclosure and testing
7. **Calibration**: Software setup and calibration

**Estimated Time Breakdown**:
- Preparation: 30 minutes
- Rod preparation: 30 minutes
- Potentiometer mod: 20 minutes
- Mechanical assembly: 30 minutes
- Electronics wiring: 45 minutes
- Final assembly: 30 minutes
- Testing & calibration: 30 minutes

---

## 📐 Stage 1: Preparation

### 1.1 3D Printed Parts Post-Processing

**Clean all printed parts**:
1. Remove any support material (if present)
2. Trim stringing or blobs with hobby knife
3. Test-fit all parts together
4. Light sanding (220 grit) on mating surfaces if needed

**Check critical dimensions**:
- Display opening: Should fit 1.47" LCD snugly
- Screw holes: Should be clear and aligned
- Bearing holes: Should fit 4mm rod with bearings

### 1.2 Install Heat-Set Inserts

**Required inserts**:
- 2× M2 inserts in display housing (for mounting to main body)
- 1× M4 insert in 9mm probe (for securing to rod)

**Installation procedure**:
1. Heat soldering iron to 200-220°C
2. Place insert on top of hole (brass side down)
3. Hold iron tip on insert top
4. Apply gentle downward pressure
5. Insert will melt into plastic and sink flush
6. Hold for 2-3 seconds, then remove iron
7. Allow to cool completely (30 seconds)
8. Verify insert is flush and secure

**Tips**:
- Don't overheat (plastic will deform)
- Keep iron perpendicular to surface
- If insert goes too deep, heat and pull out with pliers while hot

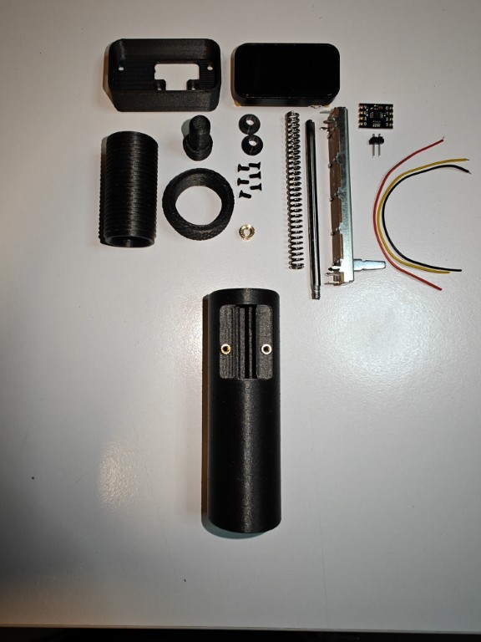
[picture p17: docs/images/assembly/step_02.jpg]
3D Printed Parts Prepared

*Photo 2: 3D printed parts with heat-set inserts installed and ready for assembly*

---

## 🔩 Stage 2: Rod Preparation

This is the most critical and tricky part of the assembly. Take your time!

### 2.1 Cut Rod to Length

**Required length**: 85mm

**Cutting procedure**:
1. Measure and mark 85mm from one end of steel rod
2. Secure rod in vise or clamp
3. Use Dremel with 1mm cutting disc
4. Cut slowly and steadily (don't force)
5. Let tool do the work (high speed, light pressure)
6. Deburr cut end with file or sandpaper

**Safety**:
- Wear safety glasses (metal particles)
- Secure rod firmly (won't slip)
- Keep hands away from cutting disc

### 2.2 Create Groove for Potentiometer Clamp

**Location**: One end of the 85mm rod  
**Depth**: Approximately 6mm  
**Purpose**: Clamps around potentiometer slider

**Grooving procedure**:
1. Mark 6mm from one end of rod
2. Secure rod in vise (groove end up)
3. Use Dremel with 1mm cutting disc
4. Cut groove perpendicular to rod axis
5. Depth: approximately 1.5-2mm (creates a slot)
6. Test fit on potentiometer slider
7. Adjust depth if needed for tight fit

**Result**: You should have a slot that can clamp onto the potentiometer slider mechanism.

### 2.3 Thread the Opposite End

**Location**: Opposite end from groove (other end of 85mm rod)  
**Thread**: M4 × 0.7mm pitch  
**Length**: Approximately 5mm

**Threading procedure**:
1. Secure rod vertically in vise (thread end up)
2. Apply cutting oil or WD-40 to rod end
3. Start M4 tap perpendicular to rod
4. Turn tap 1/4 turn clockwise
5. Back off 1/8 turn (breaks chips)
6. Repeat until 5mm depth achieved
7. Clean threads with brush
8. Test fit with M4 screw

**Tips**:
- Keep tap perfectly straight (critical!)
- Use plenty of cutting fluid
- Don't force (tap will break)
- If resistance increases, back out and clean chips

---

## 🎛️ Stage 3: Potentiometer Modification

The Bourns potentiometer needs modification to fit in the tight enclosure.

### 3.1 Trim Solder Pins

**All three pins must be trimmed as short as possible**:

1. Use flush cutters to trim pins
2. Cut as close to plastic body as possible
3. Leave approximately 1-2mm of pin
4. File smooth if needed
5. Clean any plastic burrs

**Why**: The potentiometer is a tight fit in the enclosure, long pins will interfere.

### 3.2 Trim Slider Height

**Remove approximately the height of the markings**:

1. Identify the slider mechanism (moving part)
2. Measure height of manufacturer markings
3. Use flush cutters or small saw
4. Cut slider to reduce height by ~2-3mm
5. File smooth to prevent snagging
6. Test travel (should move smoothly)

**Why**: Reduces overall height for better fit in enclosure.

### 3.3 Solder Wire to Pin 3 (Ground)

**Before installing in enclosure**:

1. Cut 15cm of wire (black recommended)
2. Strip 3mm from one end
3. Tin wire end and Pin 3 (one end pin)
4. Solder wire to Pin 3
5. Add heat shrink tubing if desired

**Why**: Pin 3 must be soldered before potentiometer is installed, as it will be inaccessible later.

**Pin identification** (looking at solder side):
```
Pin 1 [●]────────[●] Pin 3 (Ground) ← Solder wire here
        [●]
       Pin 2 (Wiper/Signal)
```

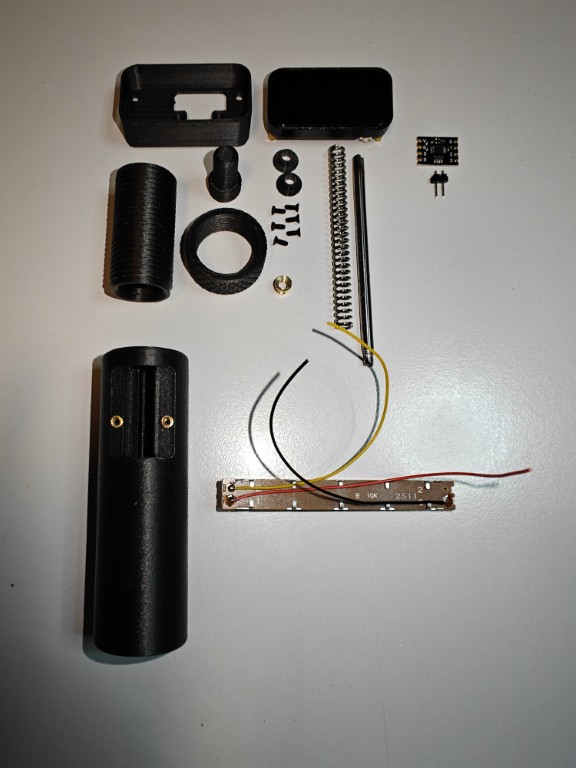
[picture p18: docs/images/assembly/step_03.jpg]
Potentiometer Wired

*Photo 3: Potentiometer with wires soldered to all three pins*

---

## ⚙️ Stage 4: Mechanical Assembly

### 4.1 Install Slide Bearings

**Location**: Main body housing

1. Insert first bearing into lower bearing hole
2. Press firmly until seated
3. Insert second bearing into upper bearing hole
4. Verify bearings are aligned (rod should slide through)
5. Test fit with rod (smooth motion)

### 4.2 Attach Rod to Potentiometer

**This requires care and patience**:

1. **Position potentiometer** in main body (don't fully insert yet)
2. **Align grooved end of rod** with potentiometer slider
3. **Clamp rod groove** around slider mechanism
   - The groove should grip the slider firmly
   - May require slight bending/squeezing of rod end
   - Use pliers if needed to tighten grip
4. **Carefully guide Pin 3 wire** through cable duct
   - Route wire along inside of enclosure
   - Avoid pinching wire
5. **Slide potentiometer** into position
   - Don't push all the way in yet
   - Leave accessible for soldering Pins 1 and 2

**Check**: Rod should move potentiometer slider when pushed/pulled.

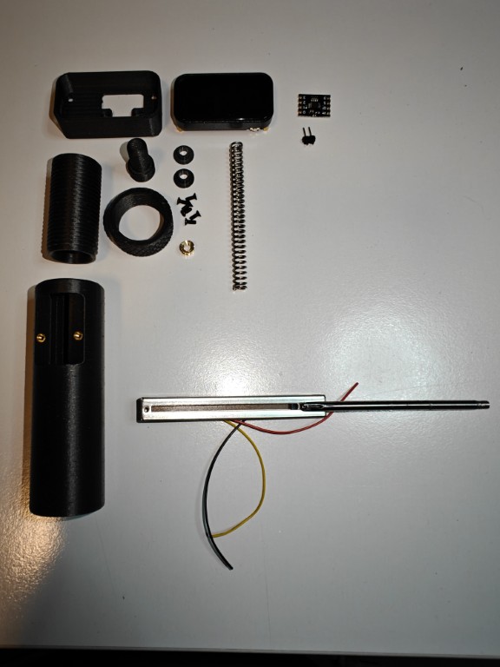
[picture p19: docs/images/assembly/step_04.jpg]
Rod Attached to Potentiometer

*Photo 4: Rod with grooved end clamped to potentiometer slider, wires attached*

### 4.3 Solder Pins 1 and 2

**Now that potentiometer is positioned**:

1. Cut two wires (~3 to 4cm each):
   - Red wire for Pin 1 (VCC)
   - Yellow/Green wire for Pin 2 (Signal)
2. Strip and tin wire ends
3. Solder red wire to Pin 1 (opposite end from Pin 3)
4. Solder yellow wire to Pin 2 (center pin)
5. Route wires through cable ducts

**Verify connections**:
- Pin 1: VCC (red wire)
- Pin 2: Signal/Wiper (yellow wire)  
- Pin 3: Ground (black wire, already soldered)

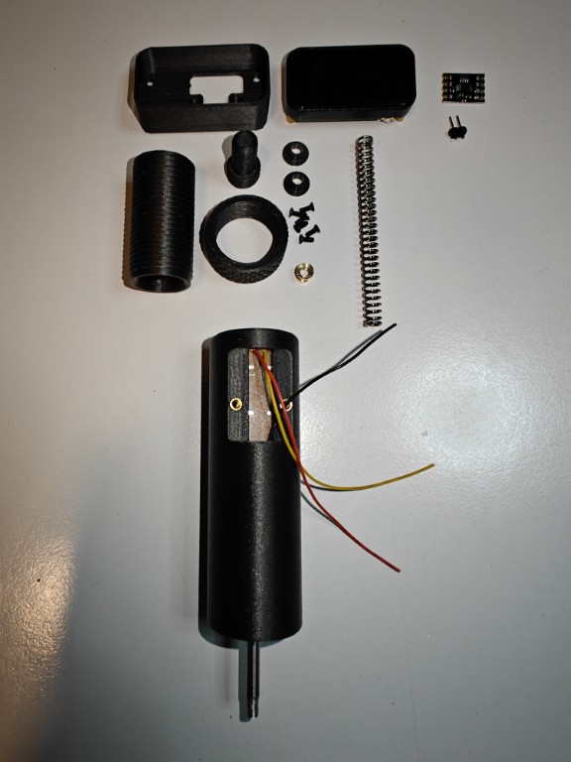
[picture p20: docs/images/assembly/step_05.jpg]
Potentiometer in Housing

*Photo 5: Rod and potentiometer installed in housing with all wires routed*

### 4.4 Secure Potentiometer with Probe Die

**Lock everything in place**:

1. Thread M4 probe die onto threaded end of rod
2. Screw in until it contacts potentiometer housing
3. This clamps potentiometer firmly in position
4. Verify potentiometer cannot move
5. Test rod travel (should be smooth, but becarefull not all of 60mm range is usuable)

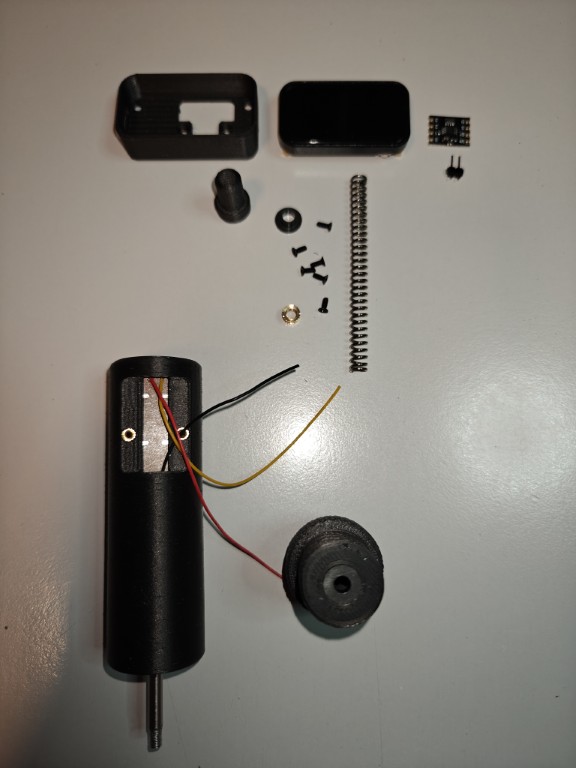
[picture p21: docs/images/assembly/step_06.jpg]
Probe Die Secured

*Photo 6: Probe die threaded onto rod, securing potentiometer in position*

### 4.5 Install Spring and Probe

**Final mechanical assembly**:

1. **Slide compression spring** over rod
   - Spring should rest against probe die
2. **Attach 9mm probe** to threaded rod end
   - Screw into M4 insert (installed in Stage 1)
   - Tighten securely but don't over-tighten
3. **Test spring action**:
   - Push probe in (should compress spring)
   - Release (should return smoothly)
   - Check for binding or rough spots

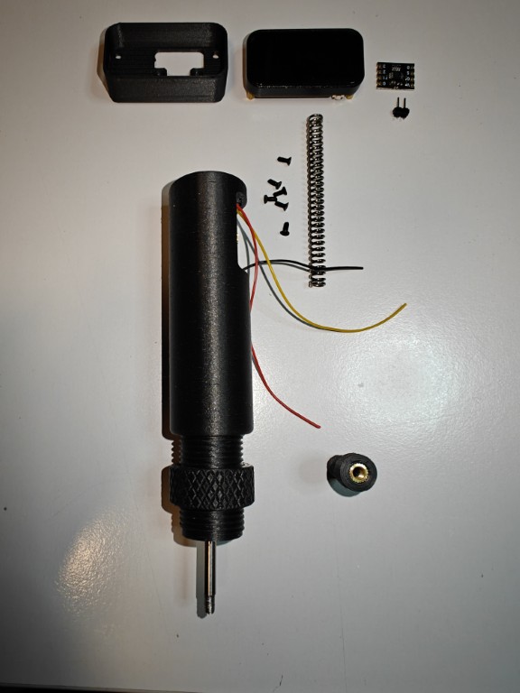
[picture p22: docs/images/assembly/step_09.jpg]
Spring and Probe Assembly

*Photo 9: Spring installed over rod with probe attached*

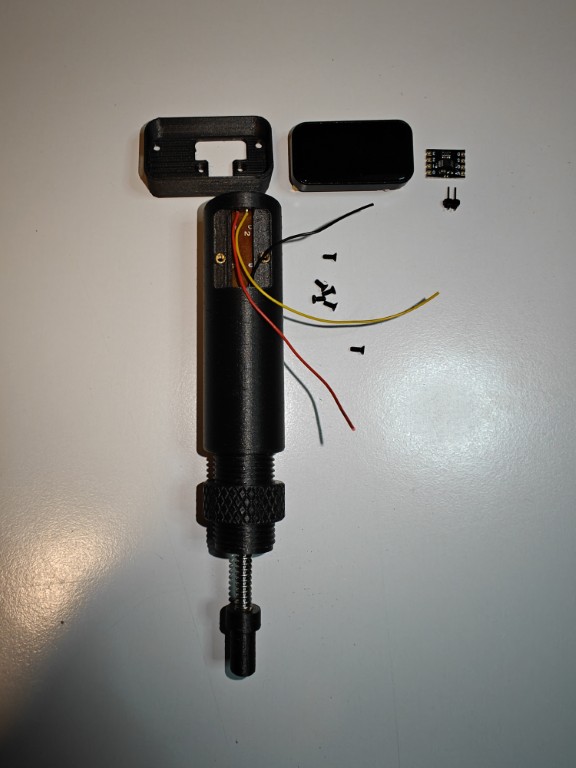
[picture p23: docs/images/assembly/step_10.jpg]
Complete Mechanical Assembly

*Photo 10: Complete mechanical assembly - rod, bearings, spring, probe, and potentiometer*

**Result**: Complete mechanical measurement assembly!

---

## 🔌 Stage 5: Electronics Assembly

### 5.1 Wiring Overview

**Connection summary**:

**Potentiometer to ADS1115**:
- Pin 1 (VCC) → 3.3V on ADS1115
- Pin 2 (Wiper) → A0 on ADS1115
- Pin 3 (GND) → GND on ADS1115

**ADS1115 to ESP32-C6**:
- VCC → VBUS (5V) or 3.3V
- GND → GND
- SCL → SCL (I2C clock)
- SDA → SDA (I2C data)

### 5.2 Potentiometer Wiring

**Connect potentiometer to ADS1115**:

1. **Pin 1 (Red wire) to 3.3v on board
   - This provides 3.3V reference voltage

2. **Pin 2 (Yellow wire) to ADS1115 A0**:
   - Solder yellow wire to A0 input
   - This is the analog signal from potentiometer

3. **Pin 3 (Black wire) to ADS1115 GND**:
   - Solder black wire to GND on ADS1115
   - Completes the voltage divider circuit

**Verify connections with multimeter**:
- Resistance between Pin 1 and Pin 3: ~10kΩ
- Resistance Pin 1 to Pin 2: 0-10kΩ (varies with position)
- Resistance Pin 2 to Pin 3: 10kΩ-0 (varies with position)

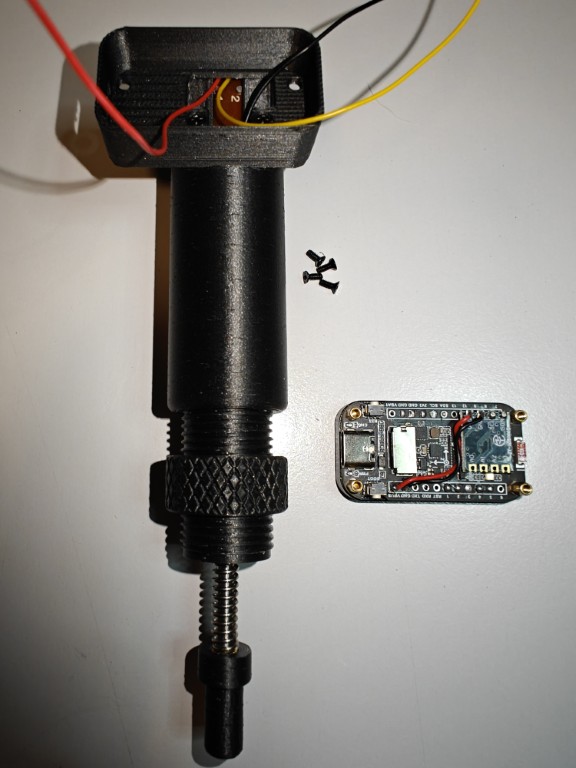
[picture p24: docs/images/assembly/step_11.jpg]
ESP32-C6 with Wiring

*Photo 11: ESP32-C6 board with potentiometer wiring connected*

### 5.3 ADS1115 to ESP32-C6 Wiring

**I2C Communication**:

1. **VCC → VBUS or 3.3V**:
   - Red wire from ADS1115 VCC
   - To VBUS (5V) or 3.3V on ESP32-C6
   - **Recommended**: Use VBUS for better ADC reference

2. **GND → GND**:
   - Black wire from ADS1115 GND
   - To any GND pin on ESP32-C6

3. **SCL → SCL**:
   - Wire from ADS1115 SCL
   - To SCL pin on ESP32-C6 (check board pinout)
   - **Default**: GPIO5 (verify in `board_config.h`)

4. **SDA → SDA**:
   - Wire from ADS1115 SDA
   - To SDA pin on ESP32-C6 (check board pinout)
   - **Default**: GPIO4 (verify in `board_config.h`)

**Board-specific notes**:
- Touch version: I2C pins may differ
- RGB version: I2C pins may differ
- Consult `src/board_config.h` for exact pin assignments

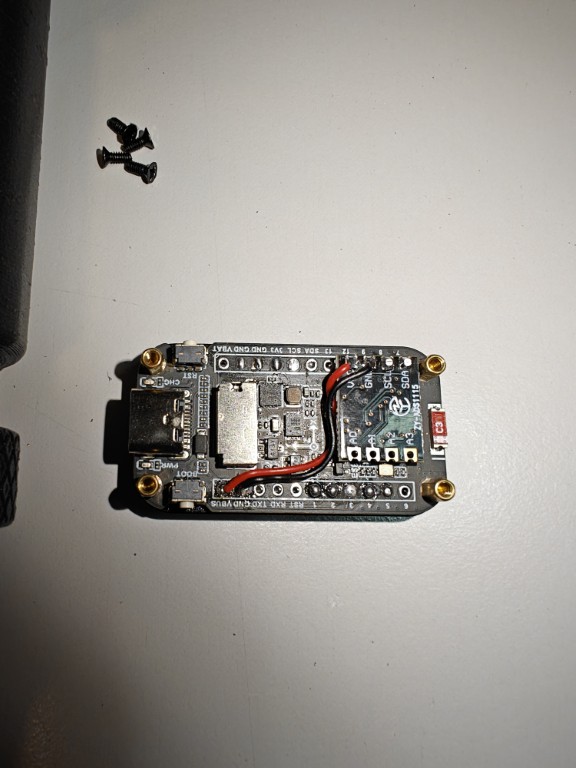
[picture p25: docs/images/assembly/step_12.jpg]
ESP32-C6 Board Detail

*Photo 12: Close-up of ESP32-C6 board showing wiring connections*

### 5.4 Soldering Best Practices

**For clean, reliable connections**:

1. **Tin all surfaces first**:
   - Apply solder to wire
   - Apply solder to pad/pin
   
2. **Heat both surfaces**:
   - Touch iron to both wire and pad
   - Apply solder to joint (not iron)
   
3. **Use proper solder amount**:
   - Enough to fill joint
   - Not so much it creates bridges
   
4. **Inspect each joint**:
   - Shiny, smooth surface (good)
   - Dull, grainy surface (cold joint, reheat)
   - Solder balls or bridges (clean and redo)

5. **Strain relief**:
   - Use hot glue for mechanical support
   - Avoid stress on solder joints

### 5.5 Testing Electronics

**Before final assembly, test all connections**:

1. **Visual inspection**:
   - Check for solder bridges
   - Verify all connections made
   - Look for cold joints

2. **Continuity test** (multimeter):
   - Verify each wire connection
   - Check for shorts between adjacent pins
   - Confirm GND connections

3. **Power test**:
   - Connect USB-C to ESP32-C6
   - Check for smoke heated up components, or unusual smells (disconnect if present!)
   - Verify board powers on (LED or display)

4. **I2C test** (optional, requires firmware):
   - Upload test firmware
   - Run I2C scanner
   - Verify ADS1115 detected at 0x48

---

## 📦 Stage 6: Final Assembly

### 6.1 Install Display

**Attach LCD to display housing**:

1. Carefully insert 1.47" TFT LCD into display bezel
2. Ensure screen is centered in cutout
3. Test display (upload firmware, verify image)

**Secure display** (choose one method):
- **Screws**: Use M2
- **Adhesive**: Use CA glue or double-sided tape (permanent)

### 6.2 Install ESP32-C6 Board

**Mount in main housing**:

1. Route display ribbon cable through opening
2. Position ESP32-C6 board in mounting area
3. Align mounting holes
4. Secure with screws
5. Ensure no wires are pinched

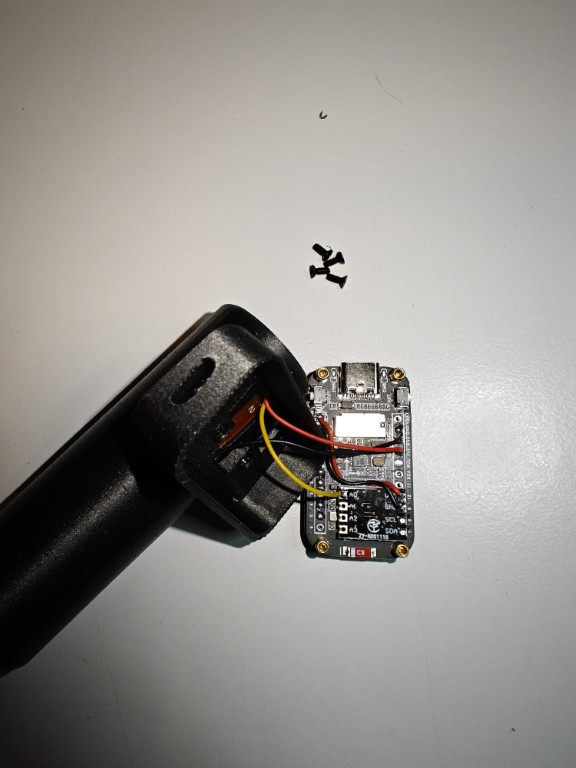
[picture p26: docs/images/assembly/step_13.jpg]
Board Installed in Housing

*Photo 13: ESP32-C6 board installed in main housing with all wiring*

### 6.3 Cable Management

**Organize internal wiring**:

1. Route all wires through designated cable ducts
2. Use cable ties or twist ties for bundling
3. Ensure no wires interfere with moving parts (rod, spring)
4. Leave some slack for movement
5. Hot glue wires for strain relief (optional)

### 6.4 Close Enclosure

**Final assembly steps**:

1. **Attach display housing to main body**:
   - Align screw holes
   - Insert M2 screws into heat-set inserts
   - Tighten evenly (don't over-tighten)

2. **Verify functionality before sealing**:
   - Power on device
   - Check display shows correctly
   - Test probe movement (should update display)
   - Verify all functions work

3. **Final enclosure assembly**:
   - Align top and bottom housing
   - Ensure all cables are inside
   - Insert M3 × 8mm screws
   - Tighten in cross pattern
   - Do not over-tighten (risk cracking plastic)

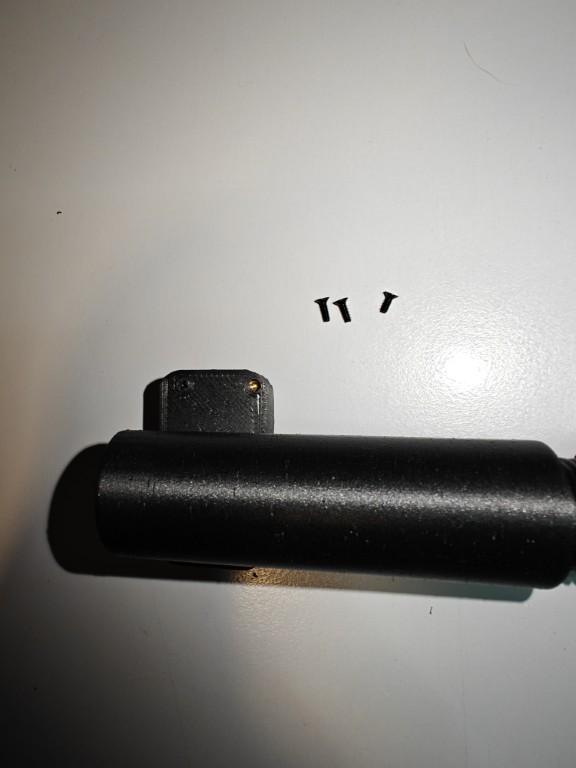
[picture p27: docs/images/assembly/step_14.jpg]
Closed Enclosure

*Photo 14: Enclosure closed and ready for testing*

---

## ✅ Stage 7: Testing & Verification

### 7.1 Power-On Test

**First boot**:

1. Connect USB-C cable
2. Device should power on immediately
3. Display should show startup screen
4. Check for any error messages

**If device doesn't power on**:
- Check USB cable (try different cable)
- Verify USB port provides power
- Check for shorts in wiring
- Inspect solder joints

### 7.2 Functional Test

**Test each function**:

1. **Display**: Should show measurement screen
2. **Probe movement**: Push probe in/out, values should change
3. **WiFi**: Device should create AP or connect to network
4. **Web interface**: Access via browser
5. **Touch/Buttons**: Test user input (if applicable)

### 7.3 Measurement Test

**Verify measurement accuracy**:

1. **Zero position**: Fully extend probe, note reading
2. **Full travel**: Fully compress probe, note reading
3. **Range**: Should be approximately 60mm
4. **Smoothness**: Move probe slowly, values should change smoothly
5. **Repeatability**: Return to same position, should read same value

**If readings are erratic**:
- Check potentiometer connections
- Verify ADS1115 is detected (I2C scan)
- Check for loose wires
- Ensure good solder joints

### 7.4 Calibration

**See [CALIBRATION.md](CALIBRATION.md) for detailed instructions**:

1. Access web interface and create a reload profile
2. Navigate to calibration page
3. Follow two-step calibration:
   - Step 1: Zero point (probe fully extended)
   - Step 2: insert case with exact amount of grains (use precision scale)
4. Save calibration
5. Verify accuracy with test measurements

---

## 🛠️ Troubleshooting

### Common Issues and Solutions

#### Issue: Rod doesn't move smoothly

**Possible causes**:
- Bearings not aligned
- Rod not straight
- Binding in enclosure

**Solutions**:
- Remove rod and check bearing alignment
- Verify rod is straight (roll on flat surface)
- Check for plastic deformation in enclosure
- Lubricate bearings with dry lubricant

#### Issue: Potentiometer doesn't respond

**Possible causes**:
- Wiring incorrect
- Solder joint failed
- Potentiometer damaged

**Solutions**:
- Verify wiring with multimeter
- Check resistance between pins (should be ~10kΩ)
- Resolder connections
- Test potentiometer separately

#### Issue: ADS1115 not detected

**Possible causes**:
- I2C wiring incorrect
- Wrong I2C address
- Faulty module

**Solutions**:
- Verify SCL/SDA connections
- Run I2C scanner (should show 0x48)
- Check for solder bridges on ADS1115
- Try different ADS1115 module

#### Issue: Display not working

**Possible causes**:
- Ribbon cable not connected
- Wrong board variant in firmware
- Display damaged

**Solutions**:
- Reconnect ribbon cable firmly
- Verify correct environment in platformio.ini
- Upload test firmware
- Check display separately

#### Issue: Measurements drift or jump

**Possible causes**:
- Poor solder joints
- Electrical noise
- Loose connections

**Solutions**:
- Reflow all solder joints
- Add capacitor across potentiometer (0.1µF)
- Shorten wire lengths
- Use shielded cable for potentiometer

---

## 💡 Tips & Tricks

### From the Designer

**Rod preparation**:
- The groove depth is critical - too shallow and it won't grip, too deep and rod weakens
- Test fit frequently while cutting groove
- Use cutting oil when threading - makes huge difference

**Potentiometer installation**:
- Take your time with this step - it's the trickiest part
- The "ingenuity" mentioned is finding the right angle to insert potentiometer while routing wire
- Don't force anything - if it doesn't fit, check what's interfering

**Soldering**:
- Use flux! Makes soldering much easier
- Clean tip frequently
- Let joints cool naturally (don't blow on them)

**Testing**:
- Test at each stage - don't wait until end
- Much easier to debug incrementally
- Take notes of any issues encountered

### Community Improvements

**Have you found a better way?**
- Share in GitHub Discussions
- Submit pull request with documentation updates
- Help improve the design for everyone!

---

## 🔄 Revision & Improvements

### Known Areas for Improvement

**Current design challenges**:
1. Rod preparation requires precision tools (Dremel, tap)
2. Potentiometer installation is fiddly
3. Wire routing in tight spaces

**Future improvements** (community suggestions welcome):
- Custom PCB to simplify wiring
- Alternative rod attachment method
- Larger enclosure for easier assembly
- Snap-fit parts instead of screws

**Your ideas?** Open an issue or discussion on GitHub!

---

## 📞 Need Help?

**Stuck during assembly?**

- **GitHub Issues**: Technical problems
- **GitHub Discussions**: Assembly questions
- **Email**: info@processware.nl

**Share your build!**
- Post progress photos
- Document any modifications
- Help others by sharing your experience

---

## ✅ Assembly Checklist

### Pre-Assembly
- [ ] All components received and verified
- [ ] 3D printed parts completed
- [ ] Tools gathered
- [ ] Workspace prepared

### Stage 1: Preparation
- [ ] 3D printed parts cleaned
- [ ] Heat-set inserts installed (M2 × 2, M4 × 1)
- [ ] All parts test-fitted

### Stage 2: Rod Preparation
- [ ] Rod cut to 85mm length
- [ ] Groove cut (6mm deep, one end)
- [ ] M4 thread cut (5mm deep, opposite end)
- [ ] Threads tested with screw

### Stage 3: Potentiometer Modification
- [ ] Solder pins trimmed short
- [ ] Slider height reduced
- [ ] Wire soldered to Pin 3 (ground)

### Stage 4: Mechanical Assembly
- [ ] Slide bearings installed
- [ ] Rod attached to potentiometer (groove clamped)
- [ ] Pin 3 wire routed through cable duct
- [ ] Pins 1 and 2 soldered
- [ ] Probe die secured
- [ ] Spring installed
- [ ] 9mm probe attached
- [ ] Smooth travel verified

### Stage 5: Electronics Assembly
- [ ] Potentiometer wired to ADS1115
- [ ] ADS1115 wired to ESP32-C6
- [ ] All solder joints inspected
- [ ] Continuity tested
- [ ] Power test passed

### Stage 6: Final Assembly
- [ ] Display installed and tested
- [ ] ESP32-C6 board mounted
- [ ] Cables organized
- [ ] Display housing attached
- [ ] Enclosure closed

### Stage 7: Testing
- [ ] Power-on successful
- [ ] Display working
- [ ] Probe movement detected
- [ ] WiFi functional
- [ ] Web interface accessible
- [ ] Calibration completed
- [ ] Accuracy verified

### Documentation
- [ ] Photos taken
- [ ] Issues documented
- [ ] Improvements noted
- [ ] Build shared with community

---

**Congratulations!** You've built your own PowderSense precision measurement system! 🎉

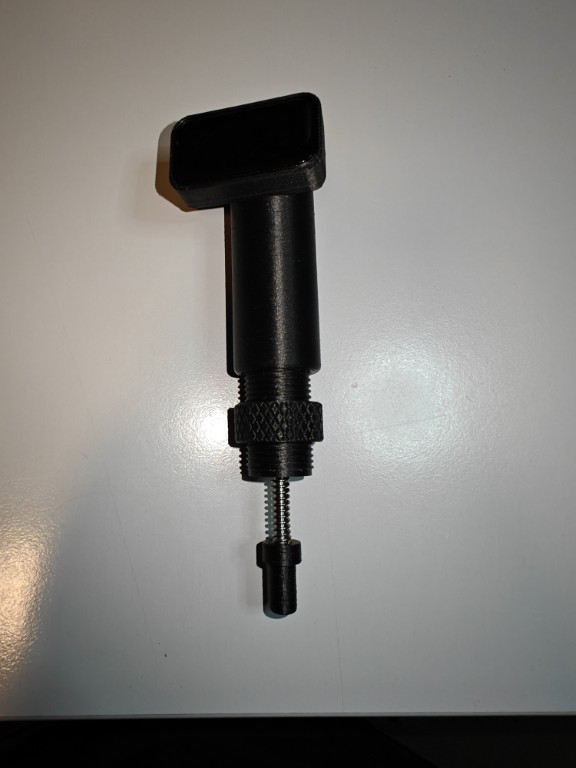
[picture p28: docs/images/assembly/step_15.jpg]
Completed PowderSense

*Photo 15: Your completed PowderSense precision measurement device*

---

*Assembly guide by Processware - November 2025*  
*Part of the PowderSense Open Source Project*

**Feedback welcome!** Help me improve this guide by sharing your build experience.

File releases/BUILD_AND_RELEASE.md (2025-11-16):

# Building and Releasing PowderSense Firmware

This guide explains how to build firmware binaries and prepare them for release.

---

## 📦 Required Files Overview

### Essential Files (Always Needed)

| File | Location After Build | Flash Address | Description |
|---|---|---|---|
| `bootloader.bin` | `.pio/build/esp32c6_touch/` | 0x0000 | ESP32-C6 bootloader |
| `partitions.bin` | `.pio/build/esp32c6_touch/` | 0x8000 | Partition table |
| `firmware.bin` | `.pio/build/esp32c6_touch/` | 0x10000 | Main application |
| `spiffs.bin` | `.pio/build/esp32c6_touch/` | 0x290000 | Web interface files |

### Optional Files (For Reference)

| File | Description |
|---|---|
| `firmware.elf` | Debug symbols (for debugging) |
| `firmware.map` | Memory map (for analysis) |

---

## 🔨 Building Firmware

### Step 1: Build Firmware

**In VS Code with PlatformIO**:
1. Open project folder
2. Click **Build** (✓ icon in status bar)
3. **OR** press `Ctrl+Alt+B`
4. Wait for compilation to complete

**Command Line** (alternative):
```bash
cd /path/to/powdersense
pio run -e esp32c6_touch
```

**Output**: Firmware files in `.pio/build/esp32c6_touch/`

---

### Step 2: Build Filesystem (SPIFFS)

**In VS Code with PlatformIO**:
1. Click PlatformIO icon (alien head) in sidebar
2. Expand **esp32c6_touch** environment
3. Expand **Platform**
4. Click **Build Filesystem Image**

**Command Line** (alternative):
```bash
pio run -e esp32c6_touch -t buildfs
```

**Output**: `spiffs.bin` in `.pio/build/esp32c6_touch/`

---

## 📂 Locating Build Files

After building, all files are in:
```
.pio/build/esp32c6_touch/
├── bootloader.bin       # ESP32-C6 bootloader (from ESP-IDF)
├── partitions.bin       # Partition table (from platformio.ini)
├── firmware.bin         # Your compiled application
├── firmware.elf         # Debug symbols
├── firmware.map         # Memory map
└── spiffs.bin           # Web interface (after buildfs)
```

**Windows Path**:
```
C:\Users\YourName\Documents\PlatformIO\Projects\powdersense\.pio\build\esp32c6_touch\
```

**Copy to Releases**:
```bash
# Windows (PowerShell)
Copy-Item .pio\build\esp32c6_touch\bootloader.bin releases\v1.0\
Copy-Item .pio\build\esp32c6_touch\partitions.bin releases\v1.0\
Copy-Item .pio\build\esp32c6_touch\firmware.bin releases\v1.0\
Copy-Item .pio\build\esp32c6_touch\spiffs.bin releases\v1.0\

# Linux/macOS
cp .pio/build/esp32c6_touch/bootloader.bin releases/v1.0/
cp .pio/build/esp32c6_touch/partitions.bin releases/v1.0/
cp .pio/build/esp32c6_touch/firmware.bin releases/v1.0/
cp .pio/build/esp32c6_touch/spiffs.bin releases/v1.0/
```

---

## 🚀 Flashing to ESP32-C6

### Method 1: Using PlatformIO (Easiest During Development)

**Upload Firmware**:
- Click **Upload** (→ icon) in status bar
- **OR** press `Ctrl+Alt+U`

**Upload Filesystem**:
- PlatformIO sidebar → **Upload Filesystem Image**
- **OR** command: `pio run -t uploadfs`

**This automatically flashes**:
- Bootloader (if needed)
- Partitions (if needed)
- Firmware
- SPIFFS (when using uploadfs)

---

### Method 2: Using esptool.py (For Manual Flashing)

**Install esptool**:
```bash
pip install esptool
```

#### Option A: Flash Everything (First Time / Clean Install)

```bash
esptool.py --chip esp32c6 --port COM3 --baud 921600 \
  --before default_reset --after hard_reset write_flash \
  -z --flash_mode dio --flash_freq 80m --flash_size 4MB \
  0x0000 bootloader.bin \
  0x8000 partitions.bin \
  0x10000 firmware.bin \
  0x290000 spiffs.bin
```

**Note**: Replace `COM3` with your port:
- Windows: `COM3`, `COM4` (check Device Manager)
- Linux: `/dev/ttyUSB0`, `/dev/ttyACM0`
- macOS: `/dev/cu.usbserial-*`

#### Option B: Flash Firmware Only (Updates)

**For firmware updates** (bootloader/partitions already on device):
```bash
esptool.py --chip esp32c6 --port COM3 write_flash 0x10000 firmware.bin
```

#### Option C: Flash Firmware + Web Interface

**Most common for updates**:
```bash
# Flash firmware
esptool.py --chip esp32c6 --port COM3 write_flash 0x10000 firmware.bin

# Flash web interface
esptool.py --chip esp32c6 --port COM3 write_flash 0x290000 spiffs.bin
```

---

### Method 3: Using ESP Flash Download Tool (Windows GUI)

**Download**: [ESP Flash Download Tool](https://www.espressif.com/en/support/download/other-tools)

**Steps**:
1. Open tool and select **ESP32-C6**
2. Add files with addresses:
   - `bootloader.bin` @ `0x0000` ✓
   - `partitions.bin` @ `0x8000` ✓
   - `firmware.bin` @ `0x10000` ✓
   - `spiffs.bin` @ `0x290000` ✓
3. Configure:
   - SPI SPEED: 80MHz
   - SPI MODE: DIO
   - FLASH SIZE: 4MB
4. Select COM port
5. Click **START**

---

## 🔍 Why Bootloader and Partitions?

### Bootloader.bin (0x0000)
- **What**: ESP32-C6 bootloader from ESP-IDF
- **Purpose**: Initializes hardware and loads firmware
- **When to flash**: 
  - ✅ First time flashing a new board
  - ✅ After erasing entire flash
  - ❌ Not needed for firmware updates

### Partitions.bin (0x8000)
- **What**: Partition table defining flash layout
- **Purpose**: Tells ESP32 where firmware, SPIFFS, NVS are located
- **When to flash**:
  - ✅ First time flashing
  - ✅ When partition layout changes
  - ❌ Not needed for firmware updates

### Firmware.bin (0x10000)
- **What**: Your compiled application code
- **Purpose**: The actual PowderSense application
- **When to flash**:
  - ✅ Every update
  - ✅ Always needed

### SPIFFS.bin (0x290000)
- **What**: Web interface (HTML/CSS/JS files)
- **Purpose**: Dashboard and configuration pages
- **When to flash**:
  - ✅ When web interface changes
  - ✅ First time setup
  - ❌ Not needed if only firmware code changed

---

## 📋 Release Checklist

### 1. Build Binaries
- [ ] Build firmware: `pio run -e esp32c6_touch`
- [ ] Build filesystem: `pio run -e esp32c6_touch -t buildfs`
- [ ] Verify no compilation errors

### 2. Test on Device
- [ ] Flash to test device
- [ ] Verify WiFi AP mode works
- [ ] Verify web interface loads
- [ ] Test calibration
- [ ] Test measurement
- [ ] Check all features work

### 3. Copy to Releases
- [ ] Copy `bootloader.bin` to `releases/v1.0/`
- [ ] Copy `partitions.bin` to `releases/v1.0/`
- [ ] Copy `firmware.bin` to `releases/v1.0/`
- [ ] Copy `spiffs.bin` to `releases/v1.0/`

### 4. Generate Checksums
```bash
cd releases/v1.0/

# Windows (PowerShell)
Get-FileHash firmware.bin -Algorithm MD5
Get-FileHash firmware.bin -Algorithm SHA256
Get-FileHash spiffs.bin -Algorithm MD5
Get-FileHash spiffs.bin -Algorithm SHA256

# Linux/macOS
md5sum firmware.bin spiffs.bin
sha256sum firmware.bin spiffs.bin
```

### 5. Update Documentation
- [ ] Update `releases/v1.0/README.md` with checksums
- [ ] Update file sizes if changed
- [ ] Update build date
- [ ] Delete `PLACE_BINARIES_HERE.txt`

### 6. Commit and Tag
```bash
git add releases/v1.0/
git commit -m "release: add v1.0 firmware binaries"
git tag -a v1.0 -m "PowderSense v1.0 - Initial Release"
git push origin master --tags
```

### 7. Create GitHub Release (Optional)
1. Go to GitHub repository
2. Click **Releases** → **Create a new release**
3. Select tag `v1.0`
4. Upload binaries as release assets
5. Copy release notes from `releases/v1.0/README.md`
6. Publish release

---

## 🔄 For Future Updates

**When releasing v1.1, v1.2, etc.**:

1. Create new directory: `releases/v1.1/`
2. Copy and update README.md and FLASHING.md
3. Build and copy new binaries
4. Update version history in `releases/README.md`
5. Tag and push

---

## 🆘 Troubleshooting

### "Bootloader.bin not found"
- Build firmware first: `pio run -e esp32c6_touch`
- PlatformIO generates bootloader automatically

### "SPIFFS.bin not found"
- Build filesystem: `pio run -e esp32c6_touch -t buildfs`
- Ensure `data/` directory exists with web files

### "Upload failed"
- Check USB cable (must support data)
- Hold BOOT button while connecting
- Try lower baud rate: `--baud 115200`
- Close other programs using serial port

### "Partition table mismatch"
- Flash partitions.bin: `esptool.py write_flash 0x8000 partitions.bin`
- Or do full erase: `esptool.py erase_flash`

---

*Build and Release Guide by Processware - November 2025*  
*Part of the PowderSense Open Source Project*

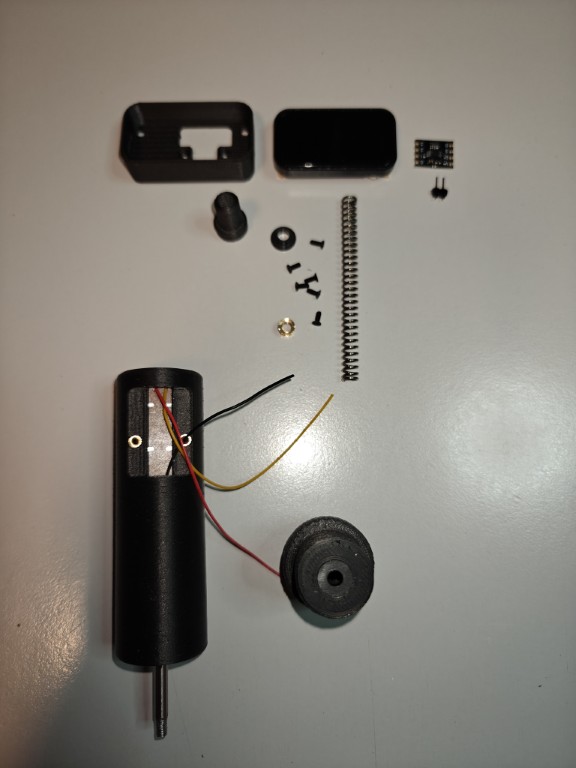
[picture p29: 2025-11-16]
docs/images/assembly/step_07.jpg

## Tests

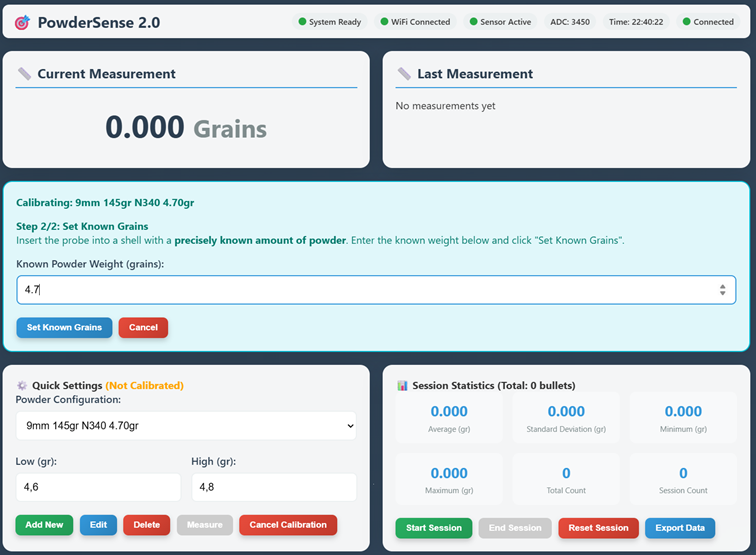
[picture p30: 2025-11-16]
docs/images/software/calibration_step2_detail.png

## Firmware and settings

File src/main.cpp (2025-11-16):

#include <Arduino.h>

#define LGFX_USE_V1
#include <LovyanGFX.hpp>
#include "board_config.h"     // ✅ Board-specific pin definitions
// #include "axs5106l_device.h"   // Temporarily disabled. Board has an AXS5106L.
#include <Wire.h>              // For I2C communication with touch controller and ADS1115
#include <WiFi.h>
#include <WebServer.h>
#include <FS.h>               // For generic File System access
#include <SPIFFS.h>           // Specifically for SPIFFS functions
#include <WebSocketsServer.h> // For WebSocket communication
#include <ArduinoJson.h>      // For JSON parsing and serialization
#include <Update.h>           // For OTA updates
#ifdef HAS_RGB_LED
  #include <FastLED.h>        // ✅ Only include if board has RGB LED
#endif
#include <DNSServer.h>        // For Captive Portal
#include <Preferences.H>      // For Non-Volatile Storage (NVS)
#include <time.h>             // For NTP time synchronization
#include <Adafruit_ADS1X15.h> // For ADS1115 ADC

// --- LovyanGFX Configuration ---
// ✅ Uses board-specific pins from board_config.h
class LGFX : public lgfx::LGFX_Device
{
  lgfx::Panel_ST7789 _panel_instance;
  lgfx::Bus_SPI      _bus_instance;
  lgfx::Light_PWM    _light_instance;

public:
  LGFX(void)
  {
    { // Configure SPI bus settings
      auto cfg = _bus_instance.config();
      cfg.spi_host = SPI2_HOST;
      cfg.spi_mode = 0;
      cfg.freq_write = 10000000;
      cfg.freq_read  = 8000000;
      cfg.pin_sclk = TFT_SCLK;  // ✅ From board_config.h
      cfg.pin_mosi = TFT_MOSI;  // ✅ From board_config.h
      cfg.pin_miso = -1;
      cfg.pin_dc   = TFT_DC;    // ✅ From board_config.h
      _bus_instance.config(cfg);
      _panel_instance.setBus(&_bus_instance);
    }

    { // Configure display panel settings
      auto cfg = _panel_instance.config();
      cfg.pin_cs           = TFT_CS;   // ✅ From board_config.h
      cfg.pin_rst          = TFT_RST;  // ✅ From board_config.h
      cfg.pin_busy         = -1;
      cfg.panel_width      = DISPLAY_WIDTH;   // ✅ From board_config.h
      cfg.panel_height     = DISPLAY_HEIGHT;  // ✅ From board_config.h
      cfg.offset_x         = DISPLAY_OFFSET_X; // ✅ From board_config.h
      cfg.offset_y         = DISPLAY_OFFSET_Y; // ✅ From board_config.h
      cfg.offset_rotation  = 0;
      cfg.dummy_read_pixel = 8;
      cfg.dummy_read_bits  = 1;
      cfg.readable         = false;
      cfg.invert           = DISPLAY_INVERT;  // ✅ Board-specific inversion
      cfg.rgb_order        = false;
      cfg.dlen_16bit       = false;
      cfg.bus_shared       = false;
      _panel_instance.config(cfg);
    }

    { // Configure backlight control
        auto cfg = _light_instance.config();
        cfg.pin_bl = TFT_BL;  // ✅ From board_config.h
        cfg.invert = false;
        cfg.freq = 44100;
        cfg.pwm_channel = 0;
        _light_instance.config(cfg);
        _panel_instance.setLight(&_light_instance);
    }

    setPanel(&_panel_instance);
  }
};

// --- Pin Definitions ---
// ✅ All pin definitions now come from board_config.h
// This keeps the code clean and board-agnostic

#ifdef HAS_RGB_LED
  CRGB leds[NUM_LEDS];  // ✅ Only define if board has RGB LED
#endif

// Initialize GFX
LGFX gfx;

// ADS1115 ADC for precise voltage measurement
Adafruit_ADS1115 ads;
bool adsInitialized = false;

// --- Double Buffering with Sprite ---
// This eliminates screen flicker by drawing to an off-screen buffer first
LGFX_Sprite canvas(&gfx);  // Create sprite buffer for smooth rendering

// Reference for drawing operations (enables double buffering)
// Use 'display' for all drawing in draw functions
LGFX_Sprite& display = canvas;

// Touch data struct
// touch_data_t touch_data; // Temporarily disabled

// --- Button Pin Definitions ---
// Removed: No longer using physical buttons

// --- Calibration and Measurement Variables ---
// These values will need to be determined through calibration
// For a spring-based potentiometer, 0mm might correspond to POT_MIN_ADC
// and 60mm to POT_MAX_ADC, or vice-versa depending on mounting.
// We'll assume 0mm is the lowest ADC reading and 60mm is the highest.
// IMPORTANT: Calibrate these values with your actual potentiometer!
// These values are now stored per-configuration in the PowderConfig struct.
// potMaxAdc is no longer used in 2-step calibration.
const float MEASUREMENT_RANGE_MM = 60.0; // 60mm travel for Bourns PTA6043-2015DPB103

// Calibration state machine
enum CalibrationState {
  CALIBRATE_NONE,
  CALIBRATE_ZERO_STEP,      // Step 1: Set probe at 0mm
  CALIBRATE_KNOWN_GRAINS_STEP // Step 2: Set probe at known grains
};
CalibrationState currentCalibrationState = CALIBRATE_NONE;
float tempZeroAdc = 0.0; // Temporary storage for zero calibration ADC value
float tempKnownGrainsDepth = 0.0; // Temporary storage for depth during known grains calibration

// --- Moving Average Filter Variables ---
const int ADC_READINGS_COUNT = 5; // Number of readings to average (reduced for faster response)
float adcReadings[ADC_READINGS_COUNT];
int adcReadingsIndex = 0;
bool adcReadingsFilled = false; // Flag to indicate if buffer is initially filled

// --- Powder Weight Conversion Factor ---
// This factor is now stored per-configuration in the PowderConfig struct as 'grainsPerMmFactor'.

// --- Wi-Fi Credentials ---
// These will be loaded from SPIFFS or configured via AP mode
String wifiSsid = "";
String wifiPassword = "";

// Preferences object for NVS
Preferences preferences;

// --- Web Server & WebSocket Server ---
WebServer server(80);
WebSocketsServer webSocket = WebSocketsServer(81); // WebSocket server on port 81
DNSServer dnsServer; // For Captive Portal

// --- Global State Variables (for web UI) ---
float currentPowderWeight = 0.0; // Placeholder for actual weight calculation

// --- OTA Update Variables ---
bool isUpdating = false;
String updateType = ""; // "firmware" or "filesystem"
size_t updateSize = 0;
size_t updateReceived = 0;

// --- Configuration Management ---
#define MAX_CONFIGS 20 // Max number of custom configurations
struct PowderConfig {
  char name[32];
  char caliber[24];
  char bulletWeight[10];
  char powderName[24];
  float targetGrain;
  // New fields for per-config calibration
  float potMinAdc;
  float grainsPerMmFactor;
  bool isCalibrated;
};

PowderConfig powderConfigs[MAX_CONFIGS];
int configCount = 0;
int currentConfigIndex = -1; // -1 means no config selected

bool alarmActive = false;
unsigned long systemUptimeMillis = 0;

// Measurement history for stats and chart
struct Measurement {
  time_t timestamp; // Epoch time (seconds since 1970-01-01)
  float weight;
  PowderConfig config; // Store a copy of the config at time of measurement
  bool configWasSet;   // Flag to know if a config was active
};
#define MAX_MEASUREMENTS_HISTORY 100 // Store up to 100 measurements
Measurement measurementHistory[MAX_MEASUREMENTS_HISTORY];
int measurementCount = 0; // Total measurements taken
int sessionMeasurementCount = 0; // Measurements in current session
float minWeight = 0.0; // Initialize with 0.0, will be set on first measurement
float maxWeight = 0.0;    // Initialize with 0.0, will be set on first measurement
float sumWeight = 0.0;

// Session log for tracking completed sessions
struct SessionLog {
  time_t startTime; // Epoch time when session started
  time_t endTime;   // Epoch time when session ended
  int bulletCount;         // Number of bullets created in session
  float totalWeight;       // Total weight measured in session
  // Store measurement indices for this session
  int measurementStartIndex; // Index of first measurement in this session
  int measurementCount;      // Number of measurements in this session
};
#define MAX_SESSION_LOGS 50 // Store up to 50 session logs
SessionLog sessionLogs[MAX_SESSION_LOGS];
int sessionLogCount = 0;
unsigned long currentSessionStartTime = 0; // Track start time of current session
int sessionStartMeasurementIndex = 0; // Track where current session measurements start

// Alarm settings
// Changed default lowThreshold to 0.0 and highThreshold to 100.0
struct AlarmSettings {
  bool enabled;
  float lowThreshold;
  float highThreshold;
} alarmSettings = {true, 0.0, 100.0}; // Initial defaults, will be overwritten by loaded settings or calibration

// --- Auto-Measurement Variables ---
const unsigned long AUTO_MEASURE_COOLDOWN_MS = 10000; // Cooldown period after a measurement (10 seconds)
unsigned long lastAutoMeasureTime = 0; // Timestamp of last auto-measurement
unsigned long autoMeasureTimerStart = 0; // Timer for stable measurement
const float AUTO_MEASURE_TOLERANCE_GRAINS = 0.1; // Tolerance for auto-measurement (+/- grains)
const unsigned long AUTO_MEASURE_STABLE_DURATION_MS = 750; // ⚡ OPTIMIZED - Reduced from 2000ms to 750ms (2.5x faster!)
const unsigned long AUTO_MEASURE_MAX_STABLE_TIME_MS = 30000; // Maximum time to stay in stable state (30 seconds) before resetting timer
bool lastMeasurementTaken = false; // Flag to prevent continuous counting at perfect level
const float RESET_MEASUREMENT_THRESHOLD = 0.1; // Weight must drop below this to allow next measurement

// --- Display Update Variables ---
unsigned long lastDisplayUpdateTime = 0;
const unsigned long DISPLAY_UPDATE_INTERVAL_MS = 100; // ✅ FASTER - Update display every 100ms (10 times per second)
// Keep track of the current screen to know when to clear fully
enum ScreenState {
  SCREEN_MEASUREMENT,
  SCREEN_CALIBRATION,
  SCREEN_AP_MODE
};
ScreenState currentScreenState = SCREEN_MEASUREMENT; // Default to measurement screen

// --- Touch Button Definitions ---
struct TouchButton {
  int x, y, width, height;
  String label;
  uint16_t color;
  bool enabled;
};

// Touch buttons for main screen
TouchButton calibrateBtn = {10, 280, 80, 30, "CAL", TFT_BLUE, true};
TouchButton profileBtn = {100, 280, 80, 30, "PROF", TFT_GREEN, true};
TouchButton settingsBtn = {190, 280, 80, 30, "SET", TFT_ORANGE, true};

// Touch buttons for calibration screen
// NOTE: These buttons are currently unused as calibration is driven by the Web UI.
// TouchButton zeroBtn = {20, 250, 100, 40, "ZERO", TFT_RED, true};
// TouchButton spanBtn = {140, 250, 100, 40, "SPAN", TFT_YELLOW, true};
// TouchButton backBtn = {260, 250, 50, 40, "BACK", TFT_DARKGREY, true};

// --- WebSocket Update Variables ---
unsigned long lastWebSocketUpdateTime = 0;
const unsigned long WEBSOCKET_UPDATE_INTERVAL_MS = 500; // Update WebSocket every 500ms for faster web UI response

// --- Stable Measurement Variables ---
unsigned long lastGreenLEDTime = 0;
bool wasGreenLED = false;
const unsigned long STABLE_MEASUREMENT_DURATION_MS = 1500; // 1.5 seconds of stable green LED for recording
bool isStable = false; // Declare isStable globally

// --- Function Prototypes ---
void setupDisplay(); // Renamed from setupOLED
float readDepthADC(); // Changed to return ADC value
float calculatePowderWeight(float adcValue); // Changed to accept ADC value
void updateLEDs(float currentWeight); // ✅ Function prototype for RGB LED support
void setupWiFi();
void startAPMode(); // New function for AP mode
void handleRoot();
void handleGetDepth(); // Will be updated to send full state
void handleApiMeasurement(); // New handler for /api/measurement fallback
void handleNotFound();
void sendCurrentStateToClients();
void handleAutoMeasure(); // New function for auto-measurement
// void displayExampleScreen(); // Removed as it's no longer used
void saveSettings(); // Save settings to SPIFFS
float calculateStandardDeviation(); // New function for standard deviation
void loadSettings(); // Load settings from SPIFFS
void saveWiFiCredentials(const String& ssid, const String& password); // Modified to use NVS
void loadWiFiCredentials(); // Modified to use NVS
void handleWiFiConfigSave(); // New function for AP mode config save
void handleWiFiConfigPage(); // New function to serve AP mode config page

// Command handlers (placeholders for now)
void handleZeroCommand();
void handleSDCommand(String action); // New command for SD card management
void handleMeasureCommand();
void handleCalibrateCommand();
void handleSelectConfigCommand(int index);
void handleSaveConfigCommand(JsonObject doc);
void handleDeleteConfigCommand(int index);
void handleSetAlarmsCommand(bool enabled, float low, float high);
void handleAcknowledgeAlarmCommand();
void handleResetSessionCommand();
void handleStartSessionCommand(); // New command
void handleEndSessionCommand(); // New command
void handleExportDataCommand(); // HTTP endpoint for CSV export
void handleExportSessionCommand(); // HTTP endpoint for session CSV export
void handleFactoryResetCommand(); // New command for factory reset
void handleUpdateFirmwareCommand(String type, String filename, size_t size); // New command for OTA updates
void handleUpdateFirmwareCommand(String type, String filename, size_t size); // New command for OTA updates
void handleImportConfigsCommand(JsonArray configs); // New command for importing configurations
void handleExportSessionDetailsCommand(int sessionIndex); // Command for exporting session details


// Calibration wizard functions
void startCalibrationWizard();
void setCalibrationZeroPoint();
void setCalibrationKnownGrains(float knownWeight);
void cancelCalibration();

// New display functions
void drawMeasurementScreen(float weight, bool alarmActive, float lowThreshold, float highThreshold);
void drawCalibrationScreen(CalibrationState state, float currentAdc, float currentWeight); // Changed to currentWeight
void drawAPModeScreen();

// Touch handling functions
void handleTouch();
bool isButtonPressed(TouchButton &btn, int touchX, int touchY);
void drawButton(TouchButton &btn, bool pressed = false);
void handleMainTouch(int x, int y);
// void handleCalibrationTouch(int x, int y); // Removed as calibration is driven by Web UI

// setCaliberName and setPowderName are removed as they are now part of dynamic configurations.
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
void loop() {
  server.handleClient(); // Handle incoming web requests
  dnsServer.processNextRequest(); // For Captive Portal
  webSocket.loop(); // Handle WebSocket events

  // Handle touch input
  handleTouch();

  systemUptimeMillis = millis(); // Update uptime

  float currentAdc = readDepthADC(); // Get ADC value
  currentPowderWeight = calculatePowderWeight(currentAdc); // Calculate weight from ADC

  // New Auto-measurement logic: triggers when weight is stable within a tolerance of the target
  // Only allows next measurement after weight has dropped below threshold
  // Skip auto-measure during calibration
  if (WiFi.getMode() == WIFI_STA && WiFi.status() == WL_CONNECTED && currentConfigIndex != -1 && currentCalibrationState == CALIBRATE_NONE) {
    float target = powderConfigs[currentConfigIndex].targetGrain;
    float lowerBound = target - AUTO_MEASURE_TOLERANCE_GRAINS;
    float upperBound = target + AUTO_MEASURE_TOLERANCE_GRAINS;

    // Check if we need to reset the measurement flag (weight has dropped to near zero)
    if (lastMeasurementTaken && currentPowderWeight < RESET_MEASUREMENT_THRESHOLD) {
      lastMeasurementTaken = false;
      Serial.println("Measurement flag reset: weight dropped below threshold.");
    }

    // Only proceed with auto-measure if last measurement has been reset
    if (!lastMeasurementTaken) {
      // Check if current weight is within the auto-measure range
      if (currentPowderWeight >= lowerBound && currentPowderWeight <= upperBound) {
          // We are inside the target range.
          if (autoMeasureTimerStart == 0) {
              // We just entered the range, start the timer.
              autoMeasureTimerStart = millis();
              Serial.printf("Entered auto-measure range [%.2f, %.2f]. Starting timer.\n", lowerBound, upperBound);
          } else {
              // Timer is already running, check if it has been stable for long enough.
              unsigned long elapsedTime = millis() - autoMeasureTimerStart;
              
              // Check for timeout: if weight has been stable for too long, reset timer to prevent stale measurements
              if (elapsedTime >= AUTO_MEASURE_MAX_STABLE_TIME_MS) {
                  Serial.printf("Auto-measure timeout: weight stable for %lu ms. Resetting timer.\n", elapsedTime);
                  autoMeasureTimerStart = 0; // Reset timer to wait for weight to drop and re-enter range
              } else if (elapsedTime >= AUTO_MEASURE_STABLE_DURATION_MS) {
                  // Stable for required duration. Check cooldown before measuring.
                  if (millis() - lastAutoMeasureTime > AUTO_MEASURE_COOLDOWN_MS) {
                      Serial.println("Auto-measure triggered! Calling handleAutoMeasure().");
                      handleAutoMeasure(); // Trigger a measurement
                      lastAutoMeasureTime = millis(); // Reset cooldown timer
                      autoMeasureTimerStart = 0; // Reset timer to prevent immediate re-triggering
                      lastMeasurementTaken = true; // Set flag to prevent continuous counting
                  }
              }
          }
      } else {
          // We are outside the target range, reset the timer.
          if (autoMeasureTimerStart != 0) {
              autoMeasureTimerStart = 0;
          }
      }
    }
  } else {
    // No config selected, not connected, or calibration active, ensure timer is reset.
    if (autoMeasureTimerStart != 0) {
        autoMeasureTimerStart = 0;
    }
  }


  // Determine the desired screen state
  ScreenState newScreenState;
  if (WiFi.getMode() == WIFI_AP) {
    newScreenState = SCREEN_AP_MODE;
  } else if (currentCalibrationState != CALIBRATE_NONE) {
    newScreenState = SCREEN_CALIBRATION;
  } else {
    newScreenState = SCREEN_MEASUREMENT;
  }

  // If screen state changes, force a full redraw and update currentScreenState
  if (newScreenState != currentScreenState) {
    Serial.printf("ScreenState changed from %d to %d. Clearing screen.\n", currentScreenState, newScreenState); // Debug print
    gfx.fillScreen(TFT_BLACK); // Clear screen completely for new layout
    currentScreenState = newScreenState;
    lastDisplayUpdateTime = 0; // Force immediate update of new screen
  }

  // Handle TFT display updates with DOUBLE BUFFERING (no more flicker!)
  if (millis() - lastDisplayUpdateTime >= DISPLAY_UPDATE_INTERVAL_MS) {
    // Draw to off-screen sprite buffer (no flicker!)
    canvas.fillScreen(TFT_BLACK);

    if (currentScreenState == SCREEN_MEASUREMENT) {
      drawMeasurementScreen(currentPowderWeight, alarmActive, alarmSettings.lowThreshold, alarmSettings.highThreshold);
    } else if (currentScreenState == SCREEN_CALIBRATION) {
      drawCalibrationScreen(currentCalibrationState, currentAdc, currentPowderWeight);
    } else if (currentScreenState == SCREEN_AP_MODE) {
      drawAPModeScreen();
    }

    // Push complete frame to display in one smooth operation (eliminates flicker!)
    canvas.pushSprite(0, 0);

    lastDisplayUpdateTime = millis();
  }
  

  // Update RGB LED based on weight (this can be more frequent as it's not a full screen redraw)
  #ifdef HAS_RGB_LED
    updateLEDs(currentPowderWeight); // ✅ Only call if board has RGB LED
  #endif

  // Periodically send state to WebSocket clients for live updates
  // Re-added this block to ensure web UI updates
  if (WiFi.getMode() == WIFI_STA && WiFi.status() == WL_CONNECTED && millis() - lastWebSocketUpdateTime >= WEBSOCKET_UPDATE_INTERVAL_MS) {
    sendCurrentStateToClients();
    lastWebSocketUpdateTime = millis();
  }

  delay(5); // Reduced delay for faster loop iteration and more responsive ADC readings
}

/**
 * @brief Initializes the display and touch controller.
 */
void setupDisplay() {
  Serial.println("setupDisplay() called."); // Debug print
  // Init Display
  if (!gfx.begin()) {
    Serial.println("gfx.begin() failed!");
    // If display initialization fails, turn LED red to indicate error
    // leds[0] = CRGB::Red; // RGB LED not present
    // FastLED.show();
    while(true) { // Halt execution if display fails
      Serial.println("Display initialization failed. Halting.");
      delay(1000);
    }
    return; 
  }
  Serial.println("gfx.begin() succeeded."); // Debug print
  gfx.setRotation(DISPLAY_ROTATION); // ✅ Board-specific rotation from board_config.h
  Serial.printf("gfx.setRotation(%d) called\n", DISPLAY_ROTATION); // Debug print
  gfx.fillScreen(TFT_BLACK);
  Serial.println("gfx.fillScreen(TFT_BLACK) called."); // Debug print

  // Backlight is handled by the LGFX config's Light_PWM instance.
  // We can set brightness here if needed.
  gfx.setBrightness(255); // Set to full brightness
  Serial.println("gfx.setBrightness(255) called."); // Debug print

  // Initialize I2C for ADS1115 ADC
  Serial.println("Initializing I2C for ADS1115...");
  Wire.begin(ADS1115_SDA_PIN, ADS1115_SCL_PIN);
  
  // Initialize ADS1115
  if (!ads.begin(ADS1115_ADDRESS, &Wire)) {
    Serial.println("Failed to initialize ADS1115! Check I2C connections.");
    Serial.println("Falling back to direct ADC on GPIO5...");
    adsInitialized = false;
    // Initialize direct ADC pin as fallback
    pinMode(LEVEL_SENSOR_PIN, INPUT);
    Serial.printf("Direct ADC initialized on GPIO%d\n", LEVEL_SENSOR_PIN);
  } else {
    Serial.println("ADS1115 initialized successfully.");
    // Set gain to ±4.096V for better precision with 3.3V signals
    ads.setGain(GAIN_TWOTHIRDS);  // ±6.144V range
    adsInitialized = true;
  }
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

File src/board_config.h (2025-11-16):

#ifndef BOARD_CONFIG_H
#define BOARD_CONFIG_H

// ========================================
// BOARD CONFIGURATION
// ========================================
// Select your board variant in platformio.ini using build_flags
// Example: -D BOARD_WAVESHARE_CLONE or -D BOARD_CUSTOM_RGB

#if defined(BOARD_ESP32C6_TOUCH)
    // ========================================
    // ESP32-C6 with Touch (Default)
    // ========================================
    #define BOARD_NAME "ESP32-C6 Touch"
    
    // Display (ST7789) Pins
    #define TFT_SCLK 1
    #define TFT_MOSI 2
    #define TFT_DC   15
    #define TFT_CS   14
    #define TFT_RST  22
    #define TFT_BL   23
    
    // Analog Input Pin (Potentiometer/Level Sensor)
    #define LEVEL_SENSOR_PIN 5
    
    // I2C Pins (for ADS1115 ADC)
    #define ADS1115_SDA_PIN 18
    #define ADS1115_SCL_PIN 19
    #define ADS1115_ADDRESS 0x48  // ADDR pin connected to ground
    #define ADS1115_CHANNEL 0     // A0 pin for VDS measurement
    
    // RGB LED - NOT PRESENT on this board
    #undef HAS_RGB_LED
    
    // Display color inversion setting
    #define DISPLAY_INVERT false
    
#elif defined(BOARD_ESP32C6_NO_TOUCH_RGB)
    // ========================================
    // ESP32-C6 No Touch with RGB LED
    // ========================================
    #define BOARD_NAME "ESP32-C6 No Touch RGB"
    
    // Display (ST7789) Pins
    #define TFT_SCLK 7
    #define TFT_MOSI 6
    #define TFT_DC   15
    #define TFT_CS   14
    #define TFT_RST  21
    #define TFT_BL   22
    
    // Display color inversion setting
    #define DISPLAY_INVERT true
    
    // Analog Input Pin (Potentiometer/Level Sensor)
    #define LEVEL_SENSOR_PIN 3  // GPIO3 (ADC1_CH3) - free pin for sensor
    
    // I2C Pins (for ADS1115 ADC)
    #define ADS1115_SDA_PIN 18
    #define ADS1115_SCL_PIN 19
    #define ADS1115_ADDRESS 0x48  // ADDR pin connected to ground
    #define ADS1115_CHANNEL 0     // A0 pin for VDS measurement
    
    // RGB LED Configuration
    // Note: HAS_RGB_LED is defined in platformio.ini build_flags
    #define RGB_LED_PIN 8
    #define NUM_LEDS 1
    
#else
    #error "No board defined! Add -D BOARD_ESP32C6_TOUCH or -D BOARD_ESP32C6_NO_TOUCH_RGB to platformio.ini build_flags"
#endif

// ========================================
// DISPLAY CONFIGURATION (Common)
// ========================================
#define DISPLAY_WIDTH  172
#define DISPLAY_HEIGHT 320
#define DISPLAY_OFFSET_X 34
#define DISPLAY_OFFSET_Y 0

// Board-specific display rotation
#if defined(BOARD_ESP32C6_TOUCH)
    #define DISPLAY_ROTATION 7  // USB connector on left, horizontal readable
#elif defined(BOARD_ESP32C6_NO_TOUCH_RGB)
    #define DISPLAY_ROTATION 1  // Landscape mode (320x172)
#else
    #define DISPLAY_ROTATION 0  // Default rotation
#endif

// ========================================
// FEATURE FLAGS (Common)
// ========================================
// Uncomment to enable features
// #define ENABLE_TOUCH_CONTROLLER
// #define ENABLE_IMU_SENSOR

#endif // BOARD_CONFIG_H

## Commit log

2025-11-16 Initial commit - PowderSense v1.0
    Open-source precision powder measurement device for ammunition reloading.
    Features:
    - ESP32-C6 based with 1.47" touch display
    - ADS1115 16-bit ADC for precision measurement
    - Web interface for calibration and monitoring
    - 3D printable PLA-CF enclosure
    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
    [default_4MB.csv, default_8MB.csv, powdersense_complete_v1.3mf]
2025-11-16 Add software interface screenshots to user manual
    - Added 7 web interface screenshots
    - Embedded screenshots in USER_MANUAL.md at relevant sections
    - Screenshots show: dashboard, configuration, calibration, and measurements
    - Visual documentation improves user experience and clarity
    Screenshots by Processware
2025-11-16 Major revision of USER_MANUAL.md - Fix errors and improve clarity
    - Removed all incorrect touchscreen/touch button references
    - Added all 5 display state screenshots (AP mode, no config, low/perfect/high)
    - Clarified that display is read-only, all control via web interface
    - Reduced length from 1325 to 603 lines (54% reduction)
    - Removed repetitive sections and consolidated information
    - Improved structure with clearer sections
    - Added proper display states section with real photos
    - Maintained all software screenshots (dashboard, config, calibration)
    - Fixed technical inaccuracies
    - Improved readability and user-friendliness
    Manual is now accurate, concise, and production-ready.
2025-11-20 Update BOM.md
    product error corrected
